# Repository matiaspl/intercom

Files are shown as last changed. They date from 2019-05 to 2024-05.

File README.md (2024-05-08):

# intercom
A githubbed version of DIY intercom system based on Murmur voice chat server and headless Mumble client running on Raspberry Pi 3 based beltpacks. It has been originally developed by Niclas Hallgren of [Institutionen för Kultur och Media](https://www.arcada.fi/sv/forskning/institutionen-kultur-och-media), [Arcada UAS](https://www.arcada.fi/en), Finland and funded by the university fund for technical education and research, TUF (Fonden för teknisk utbildning och forskning).

For more in-depth information head to https://web.archive.org/web/20231202153422/https://inside.arcada.fi/kultur-och-media/made-in-arcada-an-open-access-diy-intercom-system/ (courtesy of WebArchive) for a writeup by the author himself.

Since this project is based on unlicense license I thought saving it for future generations is worth 10 minutes of my time. I'm not the author nor am I in any way connected to the development (yet!). 

IArcada Intercom (https://www.youtube.com/watch?v=14hbYhLjQ8Y "Youtube Clip")

## What it's for
Providing communication for event production teams large and small with limited budget. Pro intercom solutions are very reliable but at the same time very expensive. Walkie-talkie PMR or UHF radios are OK and inexpensive, but they lack full-duplex partyline communication. And full duplex audio communication is a must for live TV production teams and for coordination teams on medium and large events. 

## How does it work
The soultion allows multichannel live full duplex communication over wifi networks utilizing [Mumble communication protocol](https://wiki.mumble.info/wiki/Protocol). The system has been tested with 12 beltpacks and 4 base stations, but should work with larger networks.
A single endpoint needs ~60 kb/s bandwidth, beltpacks are known to run for +18 hours on a single charge. Latency of 10-100 ms is to be expected.

## Room for improvements
- MPTCP and/or dual interface networking with gracefull failover (3G/4G + wifi)
- vibration alarm on call
- screensaver mode preventing OLED screen burn-in
- 'unlatch all' master base station button for rapid 'radio space' cleanup
- tally integration (vMix & ATEM)

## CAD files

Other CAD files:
basestation_setup/basestation_v3.f3d
beltpack_setup/beltpack_pi_2s.f3d

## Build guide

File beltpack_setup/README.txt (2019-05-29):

Files in this folder

ic_beltpack_pi3 - Python 3 files for beltpack
Gerber_Beltpack connector PCB_20181218103215.zip - Gerber files for Beltpack connector PCB
README.txt - This file
UNLICENSE - License information
beltpack_pi_2s.f3d - Fusion 360 3D case for beltpack
beltpack_rpi3.fzz - Fritzing breadboard view of beltpack
beltpack_rpi3_hardware_installation.pdf - Hardware installation guide
setup_beltpack_rpi3.pdf - Software installation guide

To open Fusion 360 files you need to download Fusion 360
https://www.autodesk.com/campaigns/fusion-360-for-hobbyists

To open Fritzing files you need to download Fritzing
http://fritzing.org/download/

Gerber files
Are sent to PCB factory for production
GerberLogix Gerber Viewver
https://www.easylogix.de/products_detail.php?prog_id=1

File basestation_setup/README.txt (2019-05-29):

Files in this folder

ic_basestation_pi3 - Python 3 files for basestation
Gerber_PCB_20181218104959.zip - Gerber files for Basestation connector PCB
README.txt - This file
UNLICENSE - License information
basestation_rpi3.fzz - Fritzing breadboard view of basestation
basestation_rpi3_hardware_installation.pdf - Hardware installation guide
basestation_v3.f3d - Fusion 360 3D case for basestation
setup_basestation_rpi3.pdf - Software installation guide

To open Fusion 360 files you need to download Fusion 360
https://www.autodesk.com/campaigns/fusion-360-for-hobbyists

To open Fritzing files you need to download Fritzing
http://fritzing.org/download/

Gerber files
Are sent to PCB factory for production
GerberLogix Gerber Viewer
https://www.easylogix.de/products_detail.php?prog_id=1

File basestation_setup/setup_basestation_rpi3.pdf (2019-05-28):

## Setup the software for the intercom base station

Requirements:
You have setup the server (Mumble, Mosquitto, Node.js) according to the server setup guide
Raspberry Pi 3 with Ethernet (tested with 3B), required hardware and software
Download the latest Raspbian Stretch Lite image from https://www.raspberrypi.org/downloads/raspbian/

This guide assumes that you are using a Windows computer but both Mac and Linux can be used (you just have to find the tools needed). The setup is tested with Raspbian Stretch Lite image built on the 2018-06-27. When copying code from the blue fields remember to check that there are no whitespace characters (invisible spaces) at the end of the lines because that can break the code.

Etcher https://etcher.io/ is recommended to write the image to the sd card. Insert the card into the Raspberry Pi, connect a keyboard and monitor and power up, after a few seconds the Raspberry will resize the partition to fill the card used and reboot. After the reboot you will see a login screen prompting for a username, use pi as username and raspberry as password. The first task is to setup the Raspberry Pi as needed. Write the command below and press enter

sudo raspi-config

You will now see a menu like this

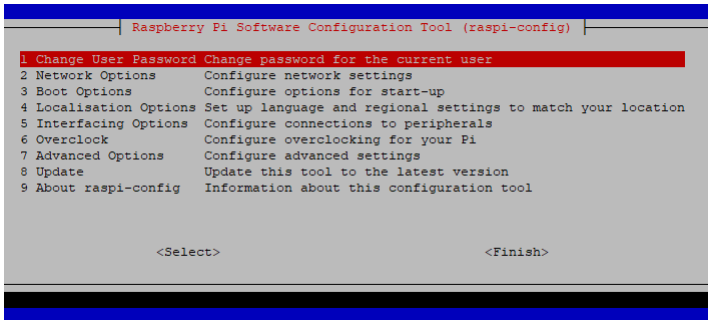
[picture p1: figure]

## 1. Configure the Raspberry

1 Change User Password (to something you remember)
2 Network Options
N1 Hostname (base stations should be named icbs1, icbs2… use icbs1 to follow this guide) 4 Localisation Options
I2 Timezone
I3 Change Keyboard-Layout
5 Interfacing options
P2 SSH Enable
P5 I2C Enable
7 Advanced options
A5 Resolution -> 1280x720 60Hz 16:9

Do NOT reboot on exit

## 2. Change I2C bus speed

sudo pico /boot/config.txt

Change line

dtparam=i2c_arm=on
to

dtparam=i2c_arm=on,i2c_arm_baudrate=400000

Save file (CTRL+x)

## 3. Set a static IP address

sudo pico /etc/dhcpcd.conf

Uncomment the example static IP configuration and use a IP that you are allowed to use
interface eth0
static ip_address=192.168.10.71/24
static routers=192.168.10.254
static domain_name_servers=8.8.8.8

Save file (CTRL+x) and reboot

sudo reboot

You should now have a IP address (look for the line My IP address is:xxxx)

You can now decide if you prefer to work with the keyboard and screen or continue the setup over SSH (using for example putty https://www.chiark.greenend.org.uk/~sgtatham/putty/ )

## 4. Update the system

sudo apt update
sudo apt dist-upgrade

### 5. Install xfce4 (a minimal graphical interface)

sudo apt install --no-install-recommends xserver-xorg
sudo apt install --no-install-recommends xinit
sudo apt install xfce4 xfce4-terminal tango-icon-theme gnome-icon-theme lightdm

## 6. Setup auto-login

sudo raspi-config

3 Boot Options
B1 Desktop / CLI
B4 Desktop Autologin

Finish and do NOT reboot

## 7. Install X11VNC

This gives a possibility to access the desktop from another computer

sudo apt install x11vnc

Set VNC password
x11vnc –storepasswd

enter desired password and save to /home/pi/.vnc/passwd

## 8. Autostart X11VNC

sudo pico /etc/xdg/autostart/x11vnc.desktop

[Desktop Entry]
Type=Application
Name=X11VNC
Comment=VNC
Icon=preferences-desktop-screensaver
Exec=x11vnc -bg -forever -noxdamage -ncache_cr -rfbauth /home/pi/.vnc/passwd TryExec=x11vnc
OnlyShowIn=XFCE;

Save file (CTRL+x)

## 9. Redirect error messages

Do not log error messages from the graphical interface to file to extend the sd card lifetime.

sudo pico /etc/X11/Xsession

point your ERRFILE to /dev/null IE. Line 77

comment out this line (add # before the line)

#exec >>"$ERRFILE" 2>&1

and add this below

exec >> /dev/null 2>&1

Save file (CTRL+x) and reboot (before this you should attach your usb sound card)

sudo reboot

## 10. Install Tightvnc

Download tightvnc on your windows computer from https://www.tightvnc.com/ -> Download, when installing choose only client.

## 11. Start Tightvnc

Start tightvnc and enter the IP number of your Raspberry Pi, you will be asked for your VNC password (set in step 7). When logged in choose “Use default config” in the popup window.

## 12. Setup audio devices

Click on the Applications button (upper left)

Applications -> Multimedia -> PulseAudio Volume Control

In the Configuration tab (press right arrow on keyboard to get to it)

bcm2835 ALSA Profile -> Off

USB Audio Device (CM108 Audio Controller) -> Analog Stereo Output + Analog Mono Input

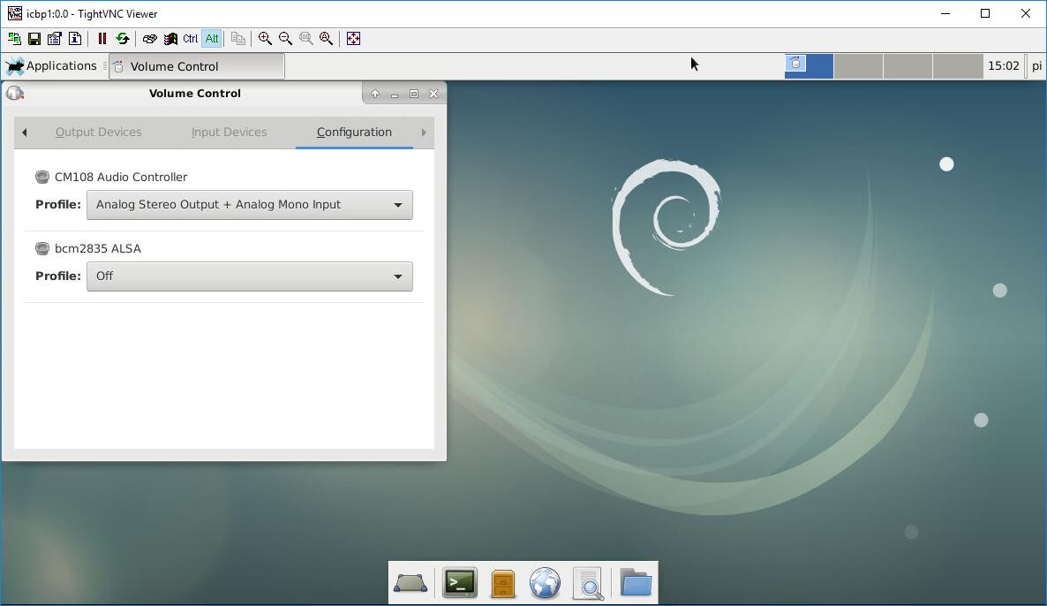
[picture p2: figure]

Close the PulseAudio Window

Enable echo cancellation for the sound card
sudo pico /etc/pulse/default.pa

add this line to the end of the file

load-module module-echo-cancel aec_method=webrtc

CTRL+x to save and reboot

sudo reboot

## 13. Create intercom folders

Go to Applications -> Terminal Emulator

mkdir ~/intercom
mkdir ~/intercom/certs
cd ~/intercom

## 14. Copy certificate files to the Raspberry Pi

The certificate was generated in the server setup guide

Download WinSCP (https://winscp.net/) on your Windows computer, install and start.

Under session choose SCP host name is your base station IP,

User name: pi, Password: (set in step 1)

When you are logged into the base station, on the left side you go to the folder where you exported the certs to in the server setup guide

On the right side you have your base station, double click intercom and then certs

Select all your certificates on the left side, right click and select Upload and OK

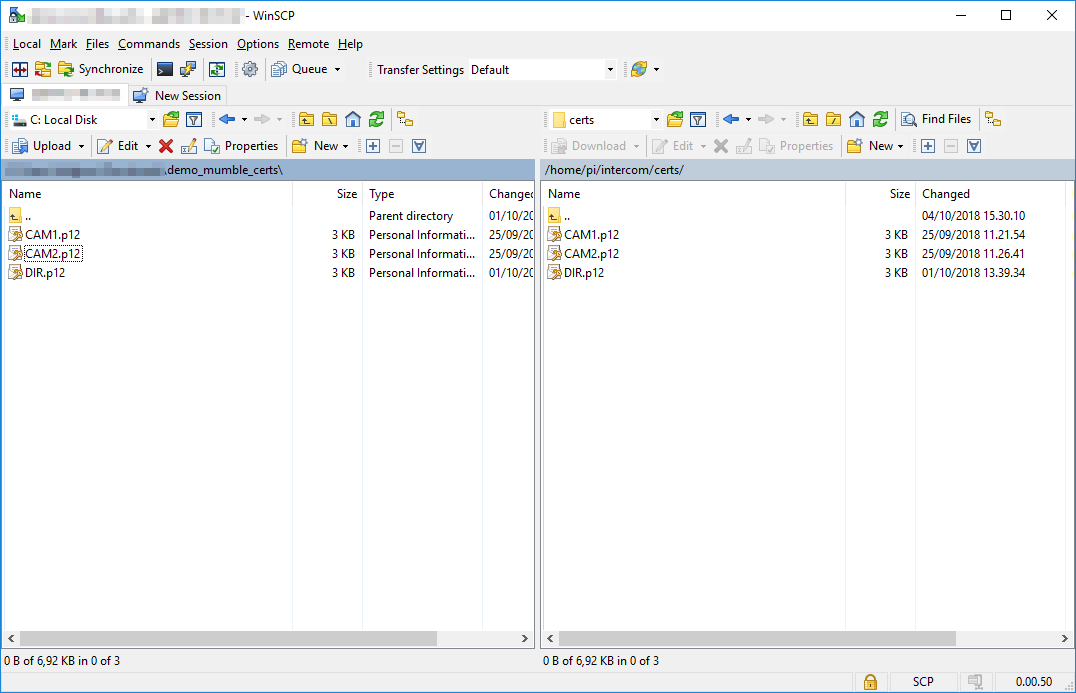
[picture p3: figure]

## 15. Install Mumble

Back to the Raspberry Pi and the terminal emulator

sudo apt install mumble

Close the terminal (click X in right corner)

## 16. Setup Mumble

When Mumble starts for the first time the Audio Tuning Wizard will appear, click next on the first introduction screen

Device selection

System: ALSA

Device [default] Playback/recording through the PulseAudio sound server

on both Input and Output device,

Uncheck positional audio -> Next

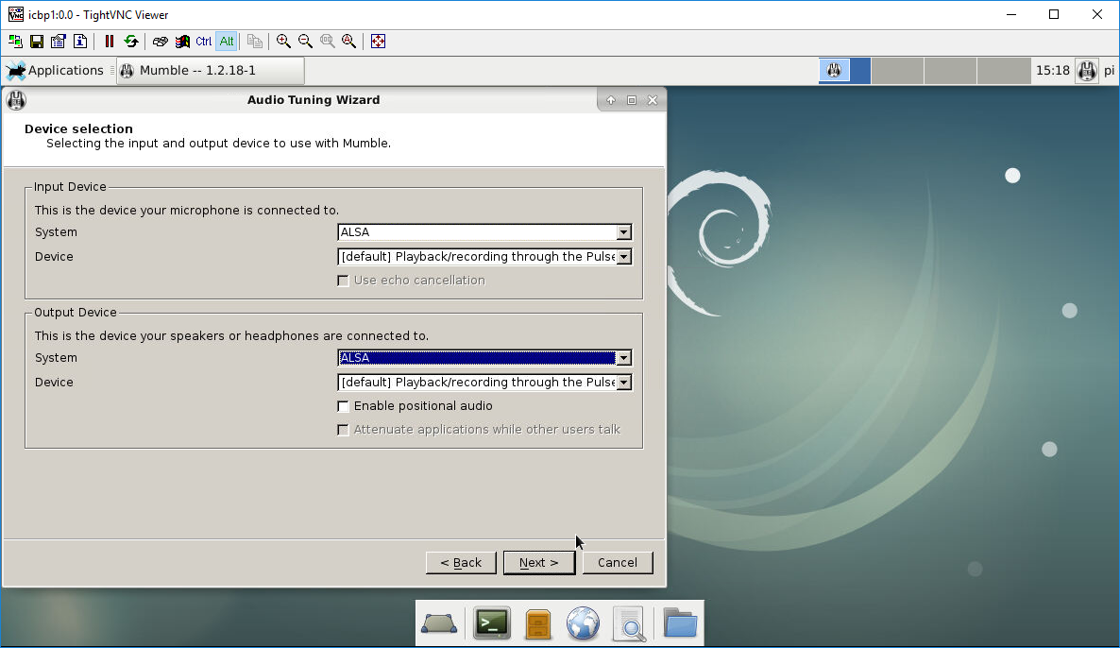
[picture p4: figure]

Set the buffer to 10ms (you will not hear anything here) -> Next

Let the microphone tuning be at its preset -> Next

Voice Acticity Detection, choose Push To Talk and click the white box next to it and press CTRL + 1 -> Next

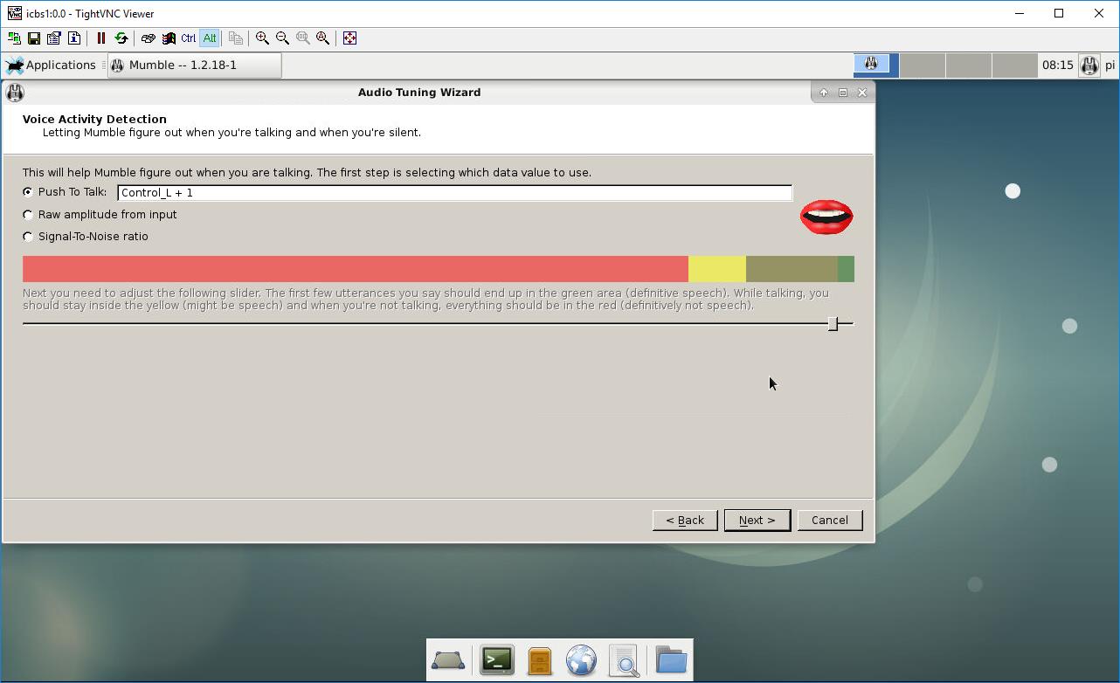
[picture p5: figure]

Quality and notifications, Quality settings -> High,

Uncheck Text-To-Speech and use sound instead -> Next

Choose if you want to submit anonymous statistics -> Finish

## 17. Import Mumble certificate

The Certificate Management should popup,

choose Import a certificate -> Next (you might have to scale the window to get to the next button)

Click Open and select the DIR certificate from /home/pi/intercom/certs/DIR.p12 -> Open -> Next

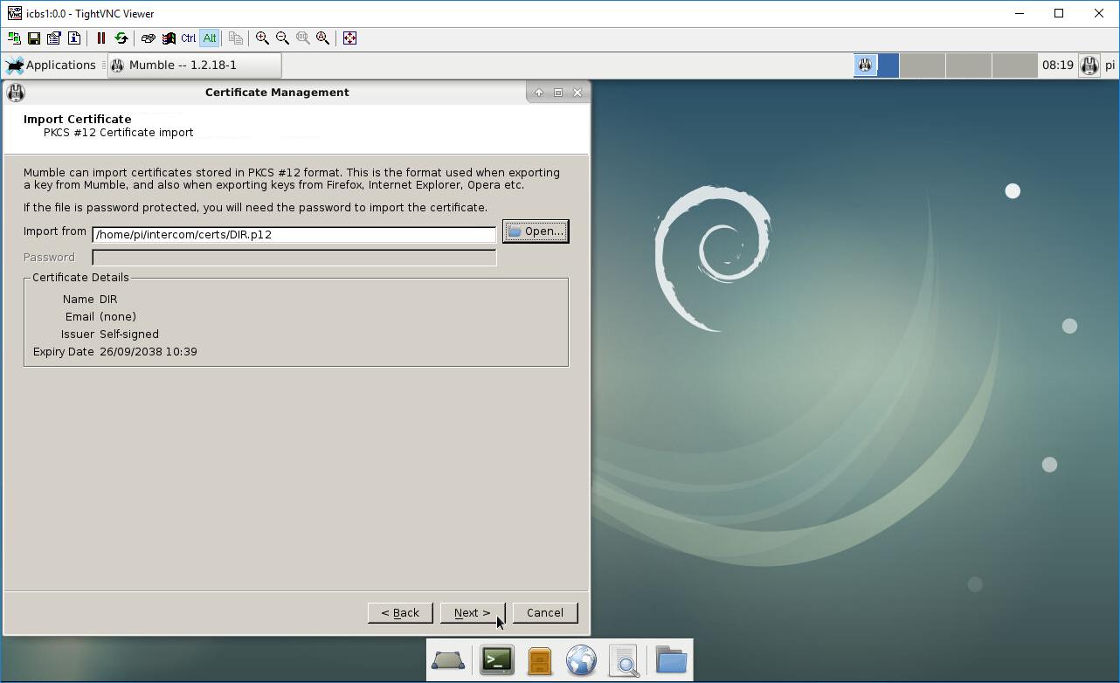
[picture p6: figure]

Click Finish

## 18. Connect to Mumble server

The Mumble Server Connect screen should have popped up, if not go to Server -> Connect

Click Add New,

Label: Intercom

Address: <YOURSERVERIP> in this example: 192.168.10.125

Port: 64738,

Username: DIR -> OK

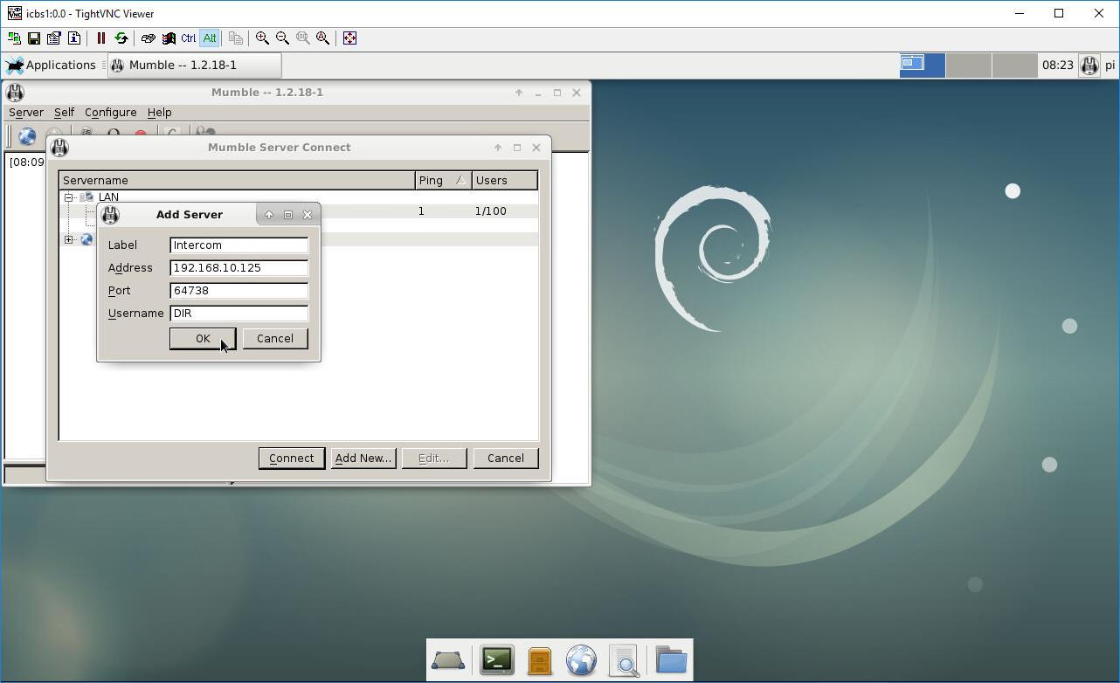
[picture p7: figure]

Under Favorite you should now see the Intercom server you just added, click Cancel and quit Mumble (Remember to ALWAYS quit/restart Mumble when making changes, settings are not saved when using power off/restart from command line).

Start Mumble again and connect to the Intercom server you just made, when you login to your server for the first time (with a new certificate) you will get a warning about the self-signed certificate, choose Yes and continue. You should now be logged in as DIR and put into the Video channel.

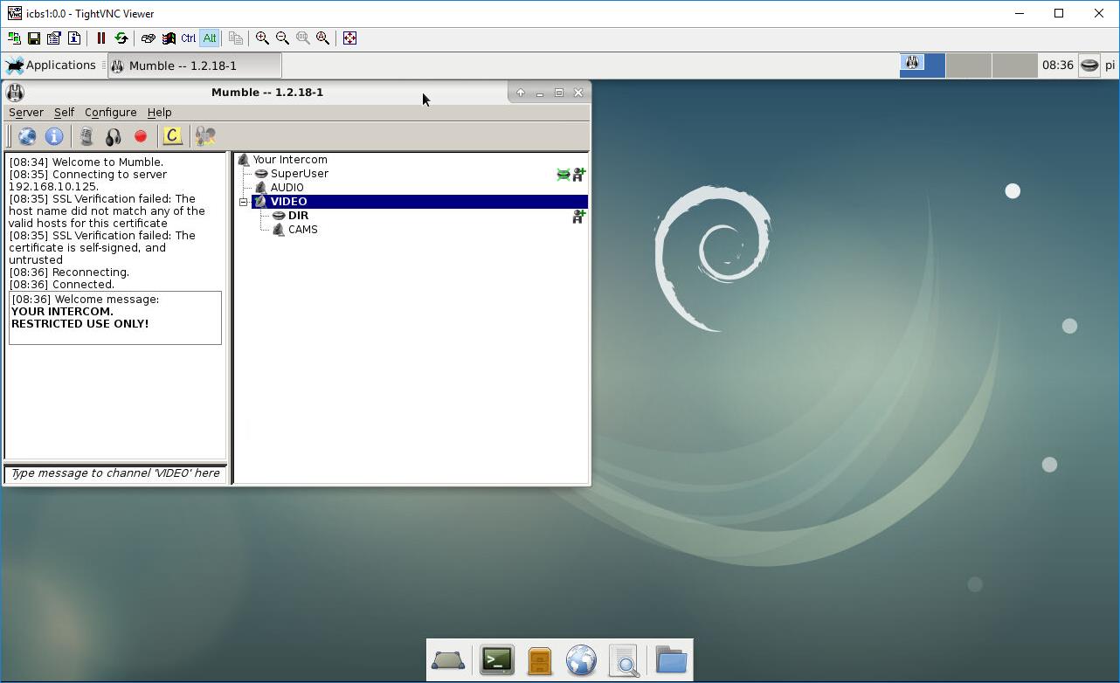
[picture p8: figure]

## 19. Configure Mumble, part 1

Under Configure->Settings->Click Advanced (down left)

Under Network, click Reconnect to last server on startup

Under Messages, set the matrix as in the picture, Notifications and Soundfile are the important ones, otherwise you will hear sounds every time a user joins/leaves a channel, etc.

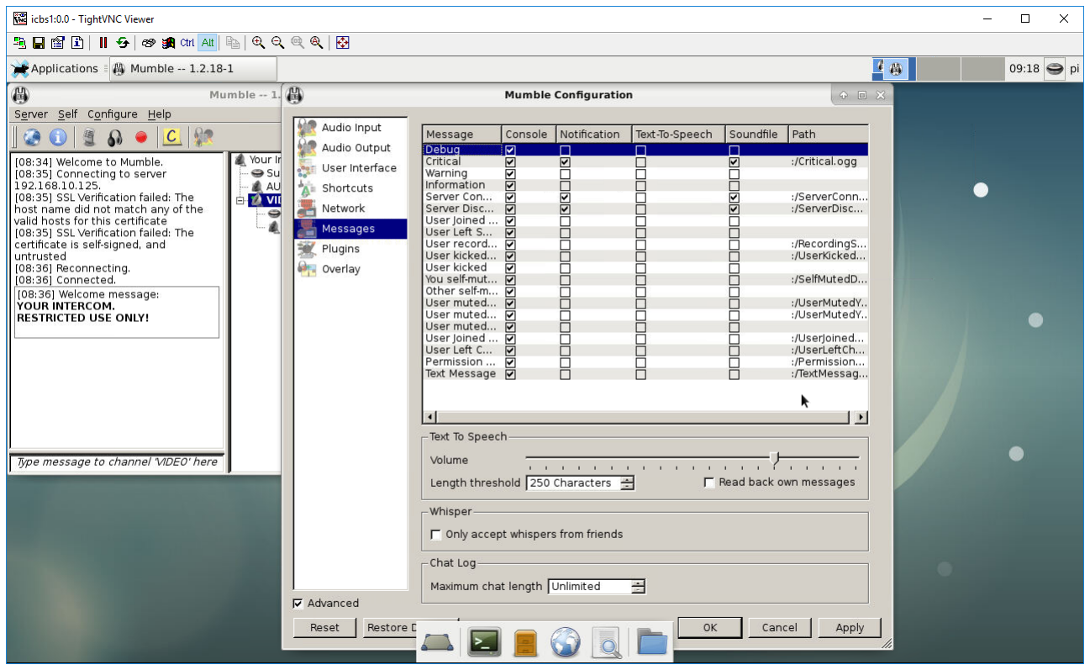
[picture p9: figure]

Apply->OK (and remember to quit/restart Mumble after this)

When Mumble is running we need to enable the echo cancellation (without a working echo cancellation the base station will get audio feedback and users talking to the base station will hear themselves if the base station is talking to them). This was setup in step 12.

Applications -> Multimedia -> PulseAudio Volume Control

Playback tab

Click USB Audio Device Analog Stereo button next to ALSA plug-in [mumble] Change dropdown ALSA Plugin [mumble] to the option that has echo cancelled.

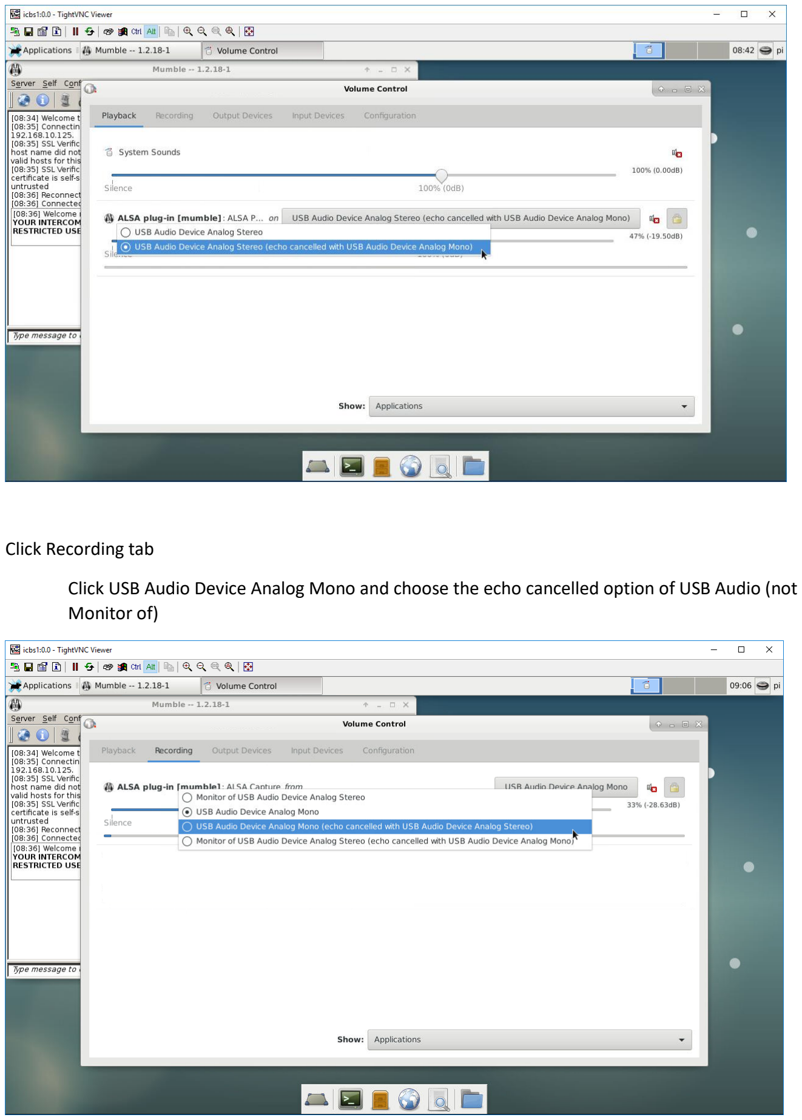
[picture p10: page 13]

Click Recording tab

Click USB Audio Device Analog Mono and choose the echo cancelled option of USB Audio (not Monitor of)

Close the Volume Control window with the X in the corner (there is no save button)

## 20. Autostart Mumble

Using Application->Terminal emulator (or using the terminal over ssh) enter the following lines

sudo pico /etc/xdg/autostart/start_mumble.desktop

[Desktop Entry]
Type=Application
Name=Mumble
Comment=Start Mumble client Icon=preferences-desktop-screensaver Exec=mumble
TryExec=mumble
OnlyShowIn=XFCE;

Save file (CTRL+x) and reboot

sudo reboot

Check (with tightvnc or screen) that Mumble starts and connects to server as DIR after reboot.

## 21. Correct session settings

Go to Applications->Settings->Session and Startup

Uncheck Automatically save session on logout under Logout Settings, and click Close

Go to Application->Terminal Emulator and write the following command

xfce4-settings-editor

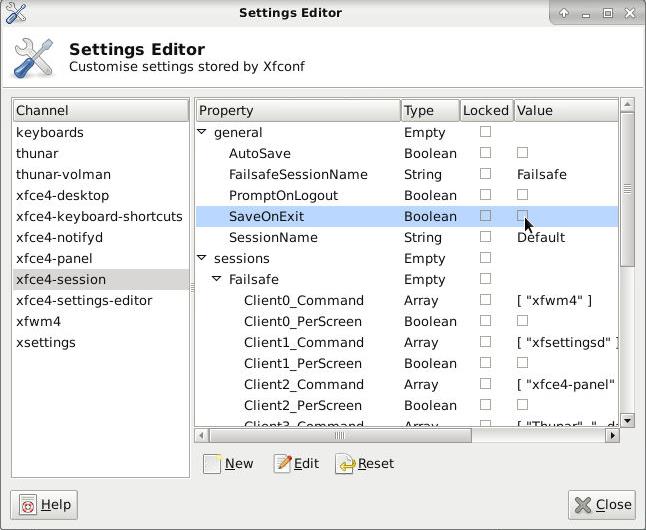
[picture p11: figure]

Under xfce4-session->Uncheck SaveOnExit if it is checked. Without this step, two Mumble clients will be running (one that is remembered from the last session and the new one that autostarts) and they will disconnect each other as only one user with that certificate can be logged in at the same time. Click Close and reboot once more to check that only one Mumble is running

sudo reboot

If everything is working, turn off the Raspberry Pi.

sudo poweroff

## 22. Install the Raspberry Pi into the enclosure

Check the base station hardware installation guide

## 23. Install python libraries

After the last step you can’t access the screen, as the Raspberry Pi is mounted in the base station enclosure. Instead you have to connect to it with putty (under hostname enter your base station IP) and click Open, login with pi and your password.

Install the OLED library
sudo apt install python3-dev python3-pip libfreetype6-dev libjpeg-dev sudo pip3 install --upgrade pip
sudo pip3 install --upgrade setuptools
sudo pip3 install --upgrade luma.oled

Install GUI automation libraries
sudo apt install libx11-dev libxtst-dev sudo pip3 install autopy3

Install MQTT library
sudo pip3 install paho-mqtt

## 24. Copy and extract base station script on Raspberry Pi

Use WinSCP on your Windows computer to copy the ic_basestation_pi3.zip file to the base station (/home/pi/intercom/ic_basestation_pi3.zip).

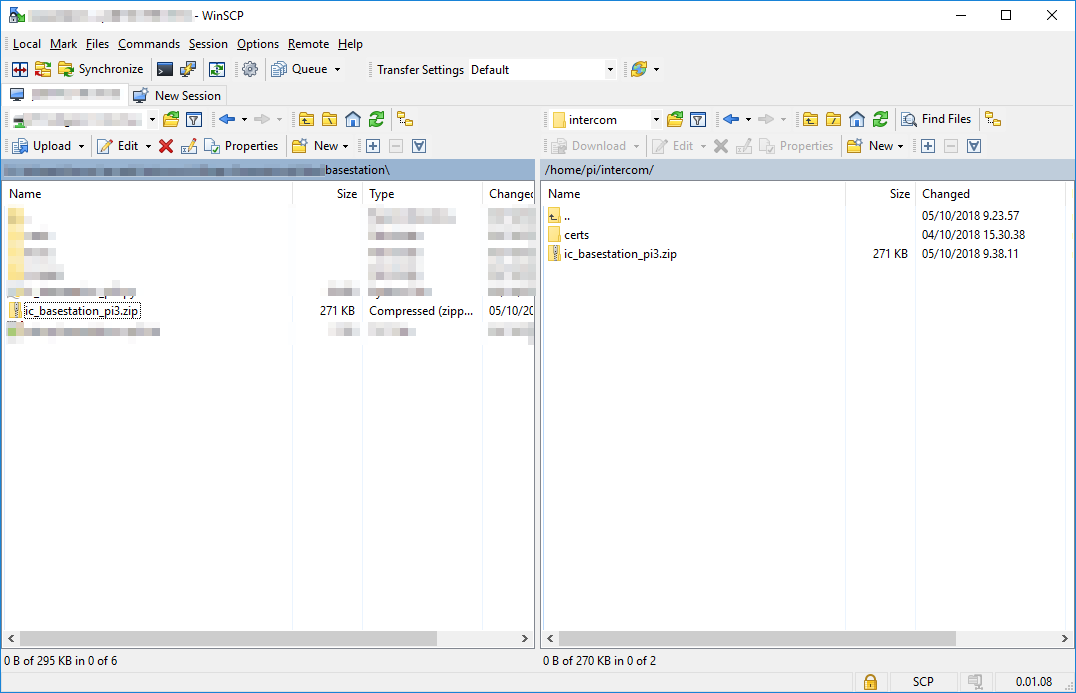
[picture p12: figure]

Back in putty

cd ~/intercom
unzip ic_beltpack_pi3.zip
rm ic_beltpack_pi3.zip

## 25. Copy MQTT server certificate

login in to your server (the example server is at 192.168.10.125)

ssh pi@192.168.10.125

(answer Yes)

Copy server cert to base station

scp /etc/mosquitto/certs/ca.crt pi@192.168.10.52:/home/pi/intercom
(replace IP with your base stations, answer yes and enter the base station password)

Disconnect from server CTRL+d and list the folder to check that the ca.crt is there

ls –la

## 26. Test the intercom script

Before you start the script you must edit it to connect to the right IP

pico ~/intercom/ ic_basestation_pi3.py

edit the following lines to match your setup:

mqttServer

mqttUser

mqttPass

Save file (CTRL+x) and start script

python3 ic_basestation_pi3.py

You should now see your IP and SRV UNAVAIL on the display. CTRL+c to quit

## 28. Make intercom startup script

pico ~/start_intercom.sh

#!/bin/bash

#START INTERCOM

DISPLAY=:1.0 XAUTHORITY=/home/pi/.Xauthority sudo /usr/bin/python3 /home/pi/intercom/ic_basestation_pi3.py &
#WAIT 30s AND SET MIC LEVEL

sleep 30
export PULSE_RUNTIME_PATH="/run/user/$(id -u)/pulse/"
# EXPERPIMENT WITH THE LAST NUMBER TO GET THE RIGHT MIC LEVEL (CAN BE DONE FROM CMD LINE) /usr/bin/pacmd set-source-volume 1 100000

observe that there should not be a line break after python3, everything should be on the same line like …/python3 /home/…

Save file (CTRL+x)

chmod +x start_intercom.sh

Make the intercom script start automatically

crontab -e

(choose 2 nano if asked)

add the following line to the end of the file

@reboot /home/pi/start_intercom.sh

CTRL+x to exit and save changes (do not change filename)

sudo reboot

After boot you should see a signal meter, the text UNKNOWN and your IP on the display

## 29. Configure the base station role

On your Windows computer open a browser and go to http://YOURSERVER_IP:3000

You now need to configure the base station, click the Wrench (the connection symbol on the left should now be green because the base station is online) on icbs1

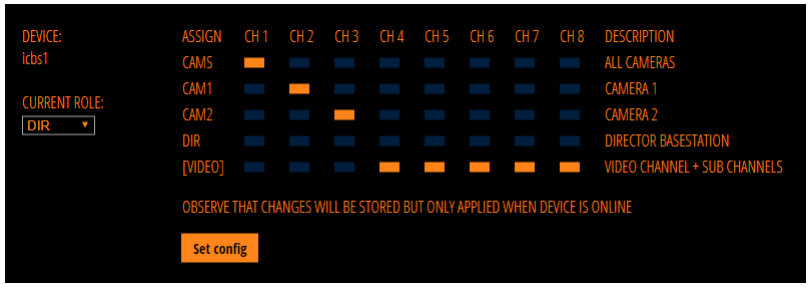
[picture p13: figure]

Select DIR as Role and the rest as the picture, click Set config

Your base station display should now be updated accordingly, it is now time to setup Mumble to match the script role and who you can talk to.

## 30. Continue to configure Mumble part 2

Connect with tightvnc to your base station, you want to talk to all cameras (CAMS) on channel 1, CAM1 on channel 2, CAM2 on channel 3 and the VIDEO channel with sub channels on 4-8. For this to work all users that you want to talk to needs to be connected to the server.

Let’s start with the CAMS channel

Under Shortcuts - > Change Push-to-Talk to Whisper/Shout (PTT transmits only the the same channel where the user is)

Under Shortcuts - > Click 3 dots under Data -> Choose Shout to channel -> Click on CAMS (UNDER VIDEO), ignore positional audio and OK

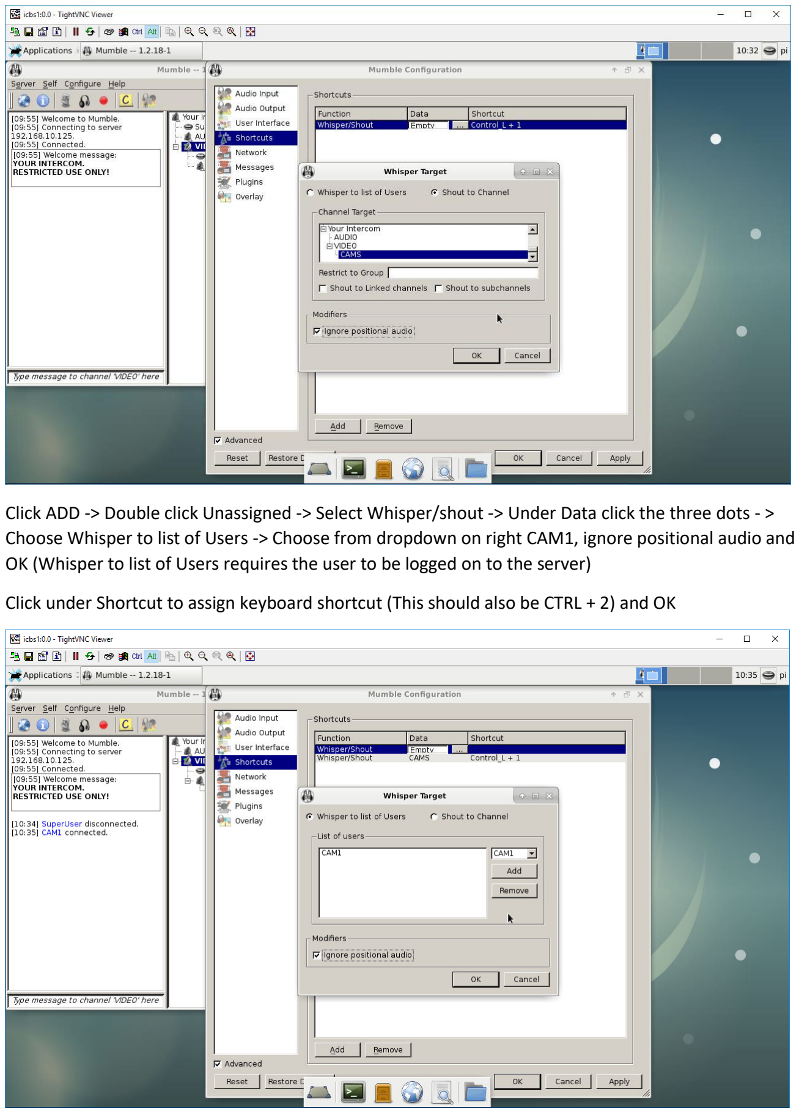
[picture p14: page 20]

Click ADD -> Double click Unassigned -> Select Whisper/shout -> Under Data click the three dots - > Choose Whisper to list of Users -> Choose from dropdown on right CAM1, ignore positional audio and OK (Whisper to list of Users requires the user to be logged on to the server)

Click under Shortcut to assign keyboard shortcut (This should also be CTRL + 2) and OK

Click ADD -> Double click Unassigned -> Select Whisper/shout -> Under Data click the three dots - > Choose Whisper to list of Users -> Choose from dropdown on right CAM2, ignore positional audio and OK

Click under Shortcut to assign keyboard shortcut (This should also be CTRL + 3)

Next we add the VIDEO channel (to channels 4-8) repeat the next steps 5 times but remember to change the shortcut CTRL+4,5,6,7,8

Click ADD -> Double click Unassigned -> Select Whisper/shout -> Under Data click the three dots - > Choose Shout to channel -> Click on VIDEO, (if you select Shout to subchannels users in both VIDEO and CAMS can hear you) ignore positional audio and OK

Click under Shortcut to assign keyboard shortcut

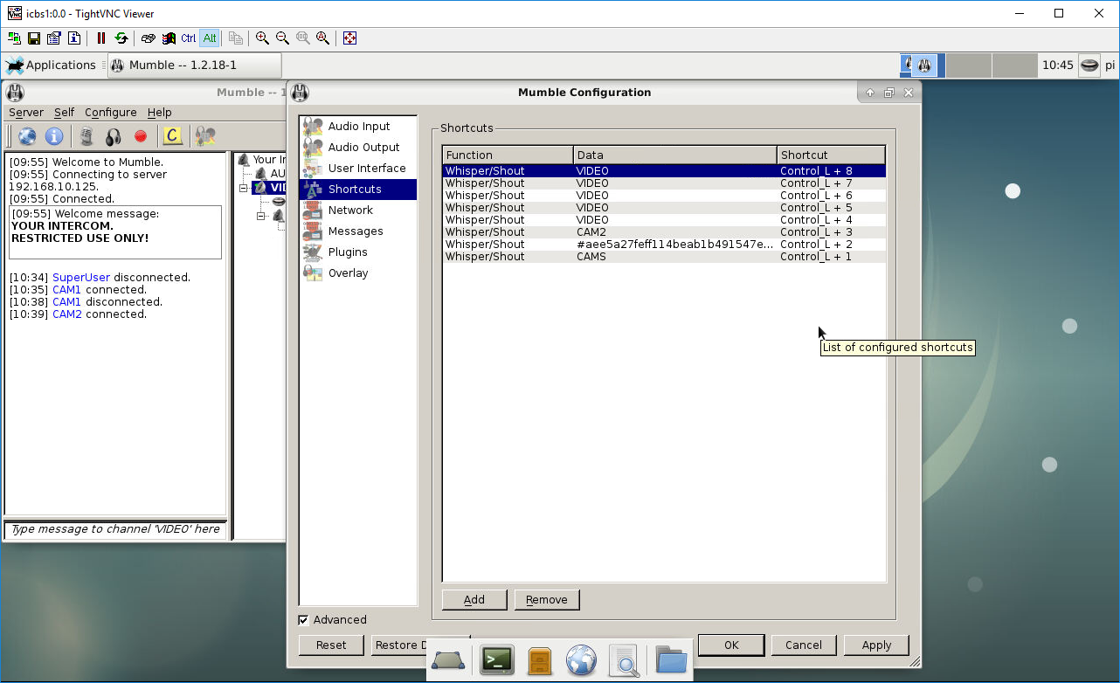
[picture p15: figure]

This is what it should look like after you are ready, in this picture CAM1 is no longer connected (had only one beltpack available when I did this guide so I had to change CAM1 to CAM2 after I assigned CAM1) and then you will see Mumbles unique id for the user. When the user is connected it will change to CAM1

Click Apply followed by OK (and remember to quit/start Mumble again)

It is possible to have own channels for users so you can use “Shout to channel” without needing the user to be online when doing the setup. Another good reason for having beltpack users in own channels are in case the beltpack user disconnects from Mumble. Mumble then stop broadcasting to that user. The python script that controls the talk buttons does not know if a user is disconnected from Mumble continues to send for example CTRL+2 (talk to CAM1), when the user connects to Mumble the users will not hear anything before the base station button is released and pressed again.

If you now hold down the first button above the display on the base station you can see that the icon before DIR turns blue (the director is talking)

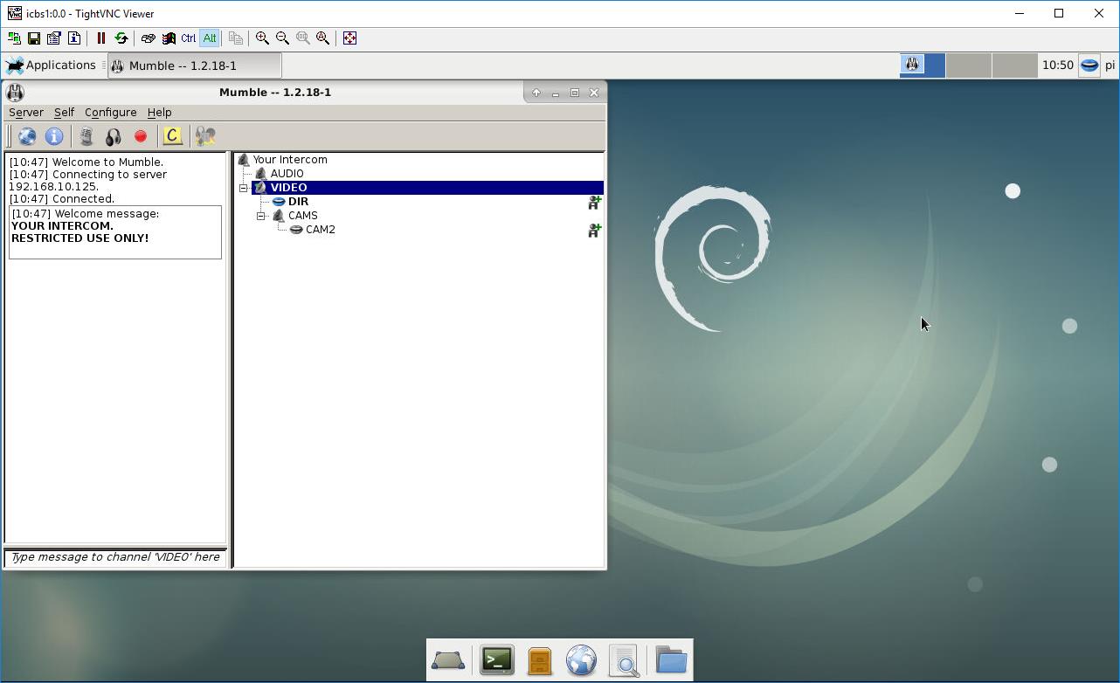
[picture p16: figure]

## 32. Conclusions

If everything works you are now ready to start using the base station. Now you can make an image of the sdcard so that you can easily duplicate it to other base stations.

Before making an image of the card, consider changing the IP, hostname and Mumble certificate to something not used normally. If you must deploy a new device during production the device the image is based on will disconnect when the new device with the same name/IP/Mumble certificate joins the network.

If you have access to a linux machine, you can use ddrescue and pishrink (replace sdc with where your sd card is found, use sudo dmsg to find out)

sudo ddrescue /dev/sdc beltpack.img rescue.log

Download and read more here https://github.com/Drewsif/PiShrink

sudo pishrink.sh beltpack.img

Pishrink (without the –s) will automatically expand to use the whole sd card when started for the first time

When you deploy the image to new devices you must remember to do the following things after deployment:

Change hostname (step 1) and IP (step 3)

Reboot to use the new name and IP

Load a new certificate in Mumble and setup who to talk to

Setup the same information in the intercom setup webgui.

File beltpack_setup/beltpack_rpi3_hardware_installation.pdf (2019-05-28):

## Assemble the intercom beltpack

Requirements:
Do not assemble the beltpack before told so in the Setup your intercom beltpack guide List of needed parts can be found in the end of this guide.

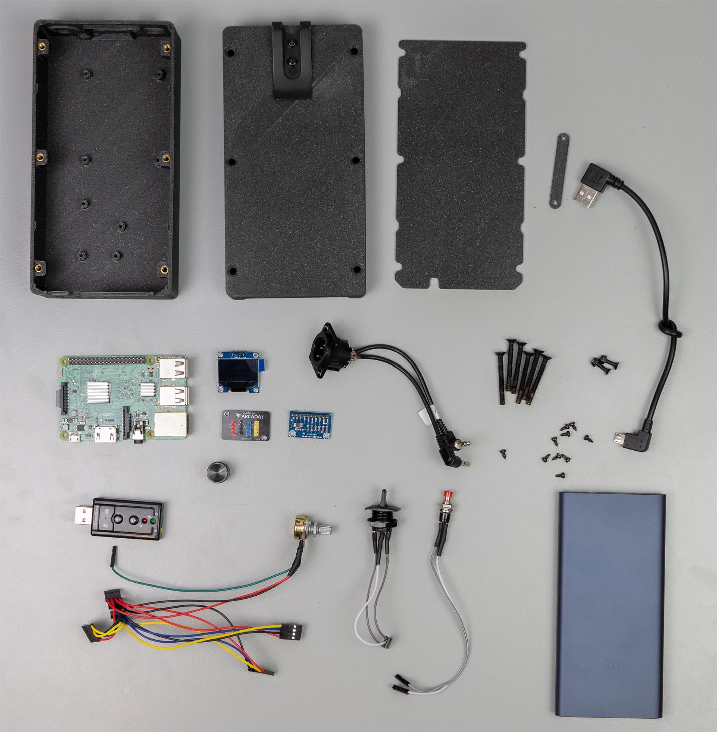
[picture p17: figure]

## 1. Insert brass insert nuts

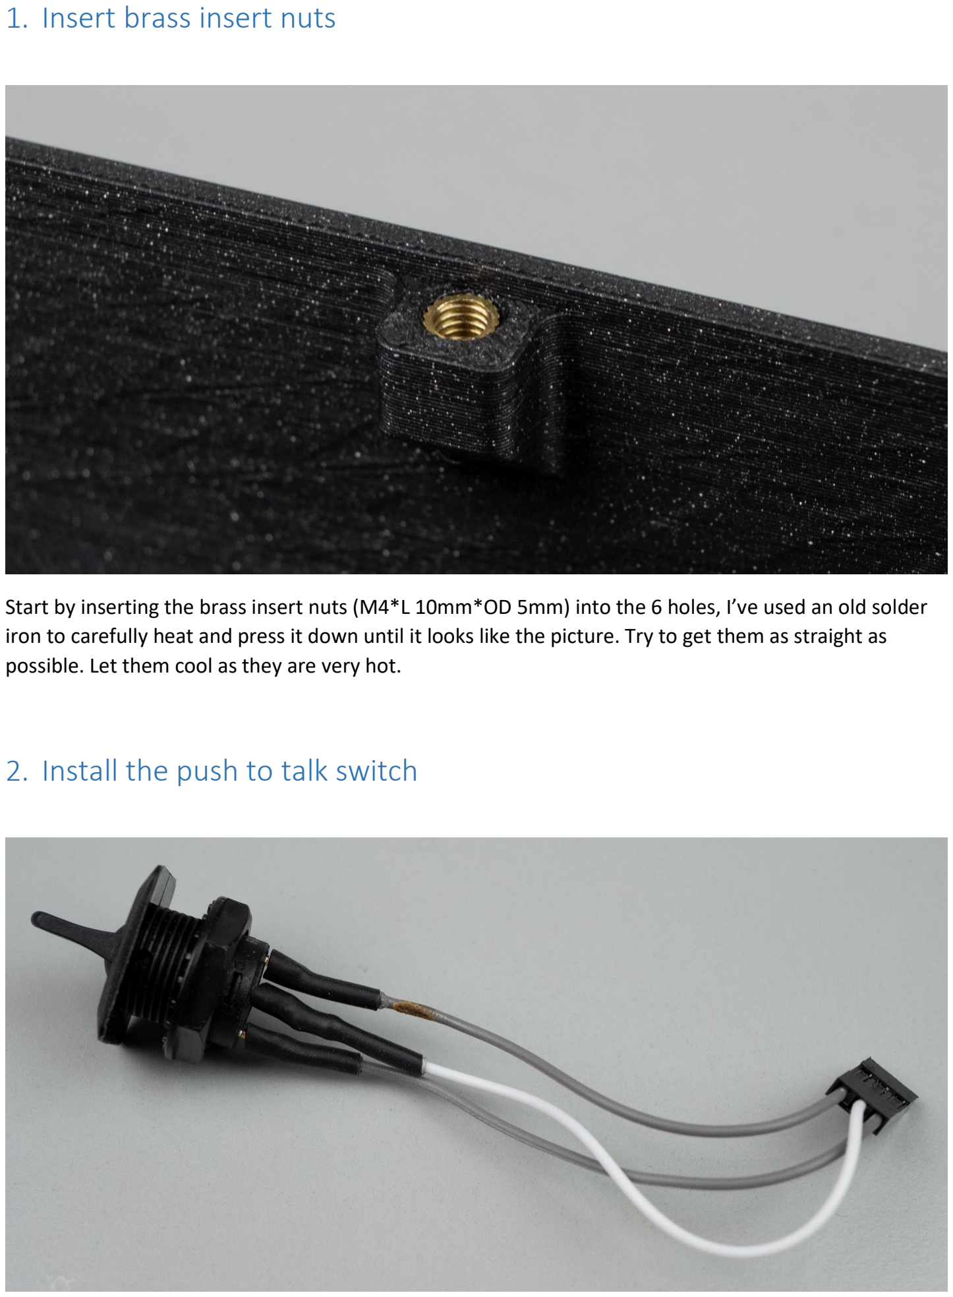
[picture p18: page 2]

Start by inserting the brass insert nuts (M4*L 10mm*OD 5mm) into the 6 holes, I’ve used an old solder iron to carefully heat and press it down until it looks like the picture. Try to get them as straight as possible. Let them cool as they are very hot.

## 2. Install the push to talk switch

The talk switch has off in the middle and talk to left and right (2 channels). In the picture the white cable provides 3.3V and has a 1k resistor soldered to the middle pin. This is to provide a little protection for the Raspberry in case it is connected to the wrong pin. The heat shrink tube to cover the pins, the other side is inserted into a 3 pin Dupont connector. Hint: Be careful not to melt the cable insulation as I did.

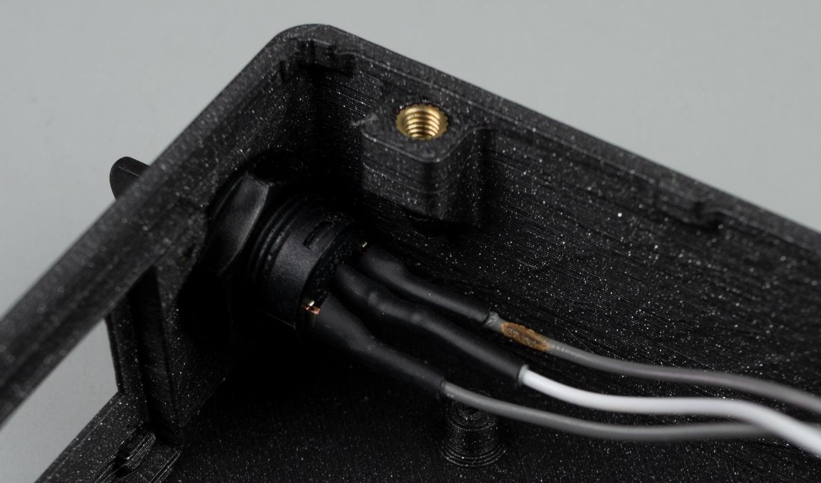
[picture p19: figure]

Insert the switch as shown.

## 3. Installing the XLR headset connector

Take a 3.5mm right angled cable and cut it in half (12-13cm should be enough but check before you cut), solder it to the XLR connector. XLR Pin 1 is connected to ground (check with a multimeter which color it is) on the 3.5mm plug that goes to the microphone on the soundcard and pin 2 is the microphone, solder the 2 remaining wires in the cable to that pin. Pin 3 is ground for the headphones and pin 4 to the left and right channels. Insert the cables through the XLR connectors hole and fasten with M3 screws and use M3 lock nuts on the inside.

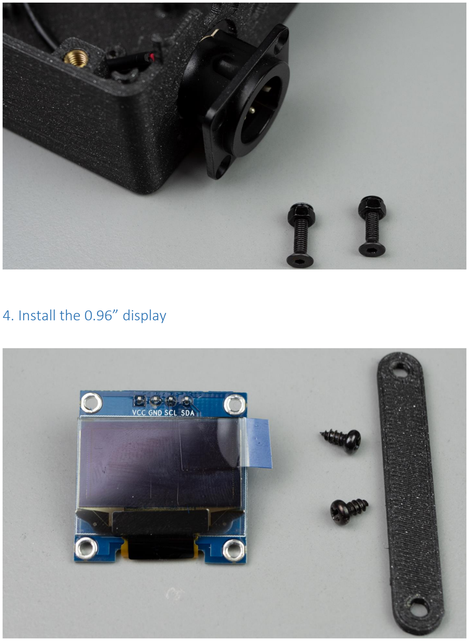
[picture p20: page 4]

## 4. Install the 0.96” display

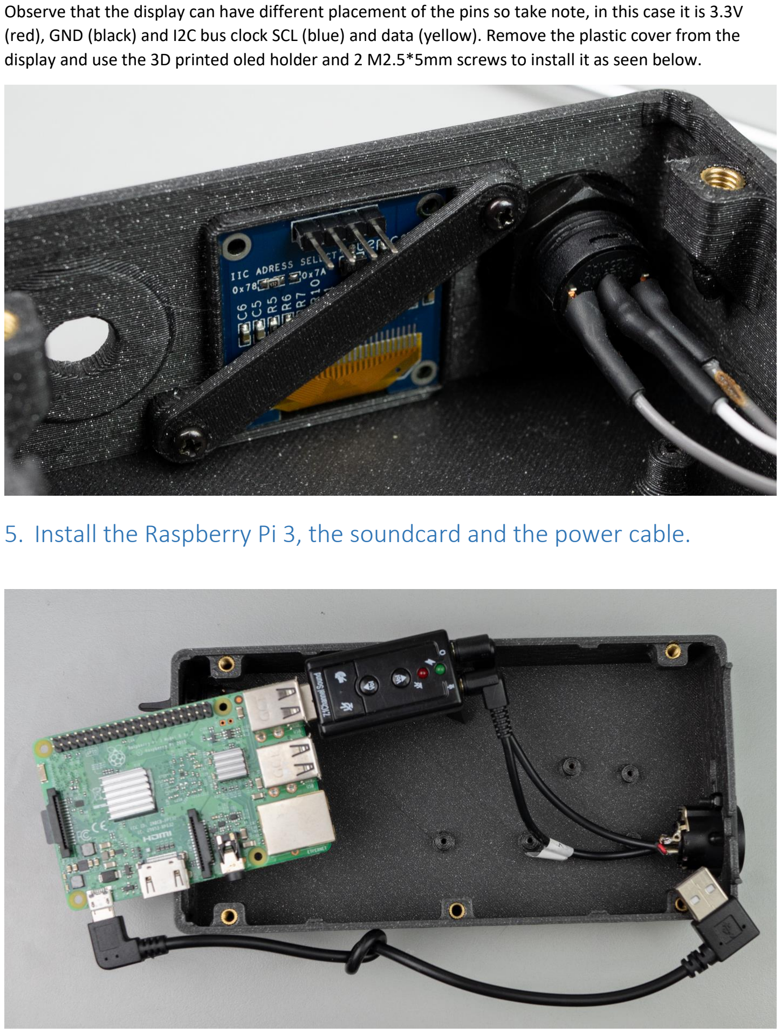
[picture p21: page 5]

Observe that the display can have different placement of the pins so take note, in this case it is 3.3V (red), GND (black) and I2C bus clock SCL (blue) and data (yellow). Remove the plastic cover from the display and use the 3D printed oled holder and 2 M2.5*5mm screws to install it as seen below.

5. Install the Raspberry Pi 3, the soundcard and the power cable.

Plug the micro USB cable into the Raspberry Pi, attach the USB soundcard and connect the 3.5mm cables from the XLR connector. Two heatsinks are installed to make the Raspberry run a bit cooler. Observe that in this guide the headphone and microphone cables are accidentally reversed in the soundcard. Carefully position the whole package into the enclosure and fasten the Raspberry Pi with 4 M2.5 (5mm) screws.

## 6. Connect the push to talk switch

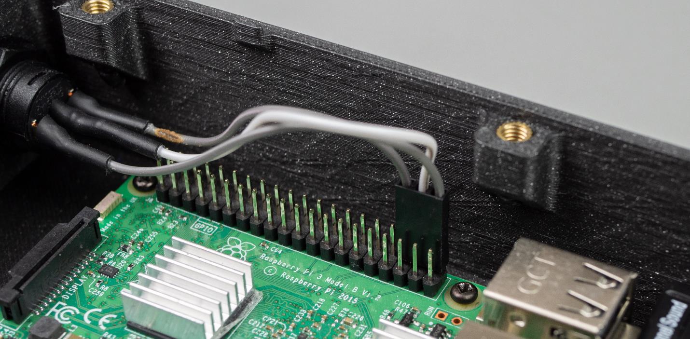
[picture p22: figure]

Connect the switch to pins 36,38 and 40 on the Raspberry Pi.

## 7. Install the breakout board and analog to digital converter

Because we need to split power and the I2C bus to multiple places I made a small PCB for the connectors but you can also use a prototype pcb to solder the connectors on, to the right the ADC for the volume control.

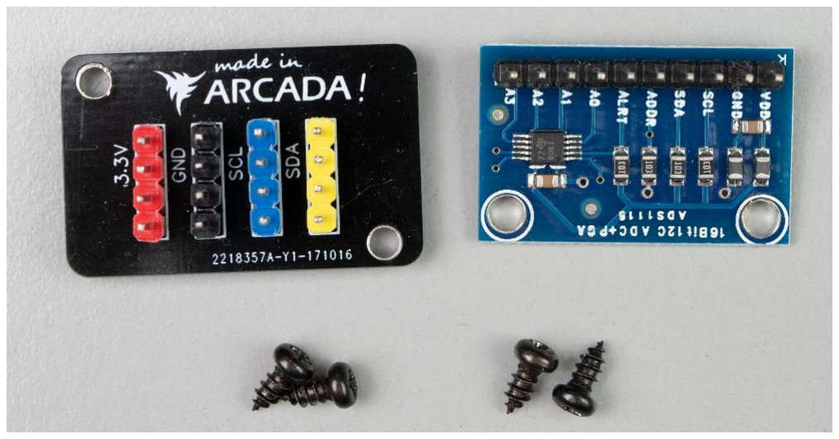
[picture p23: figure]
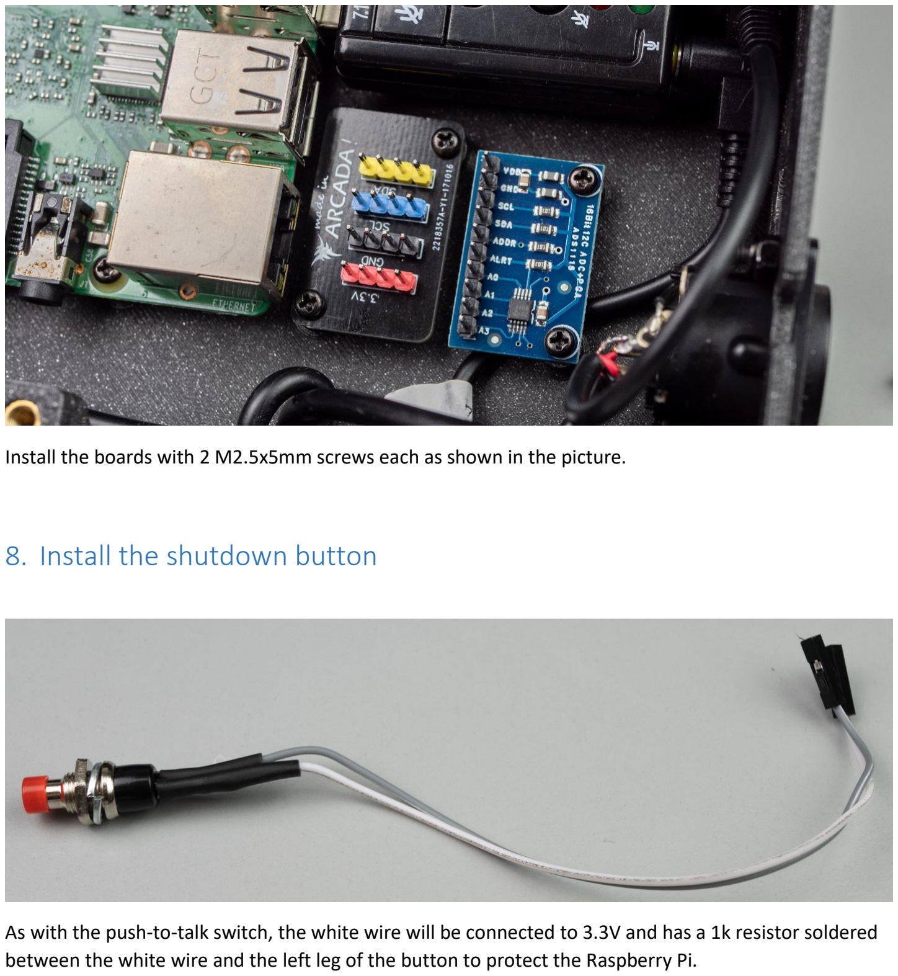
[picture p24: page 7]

Install the boards with 2 M2.5x5mm screws each as shown in the picture.

## 8. Install the shutdown button

As with the push-to-talk switch, the white wire will be connected to 3.3V and has a 1k resistor soldered between the white wire and the left leg of the button to protect the Raspberry Pi.

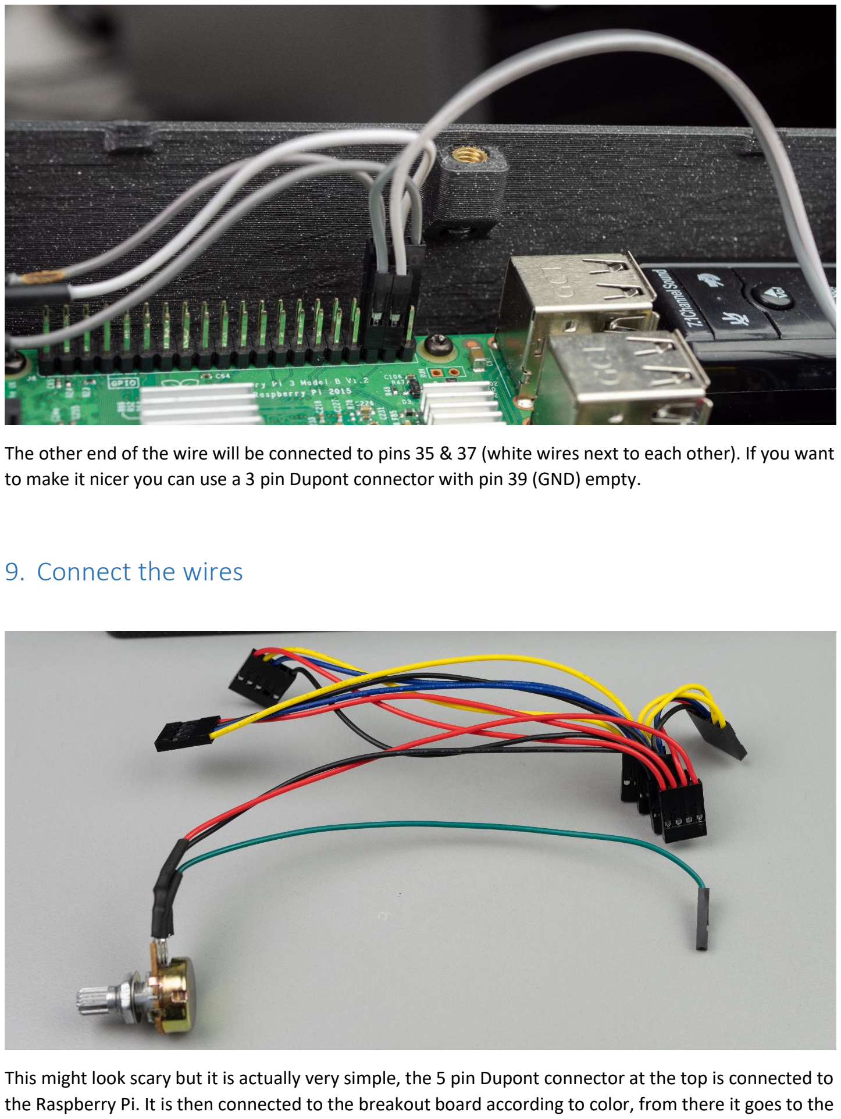
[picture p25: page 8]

The other end of the wire will be connected to pins 35 & 37 (white wires next to each other). If you want to make it nicer you can use a 3 pin Dupont connector with pin 39 (GND) empty.

## 9. Connect the wires

This might look scary but it is actually very simple, the 5 pin Dupont connector at the top is connected to the Raspberry Pi. It is then connected to the breakout board according to color, from there it goes to the

ADC, the display and the volume control board. Let’s take it step by step. You do not need to use multipin Dupont connectors but it makes them stay better and are easier to connect.

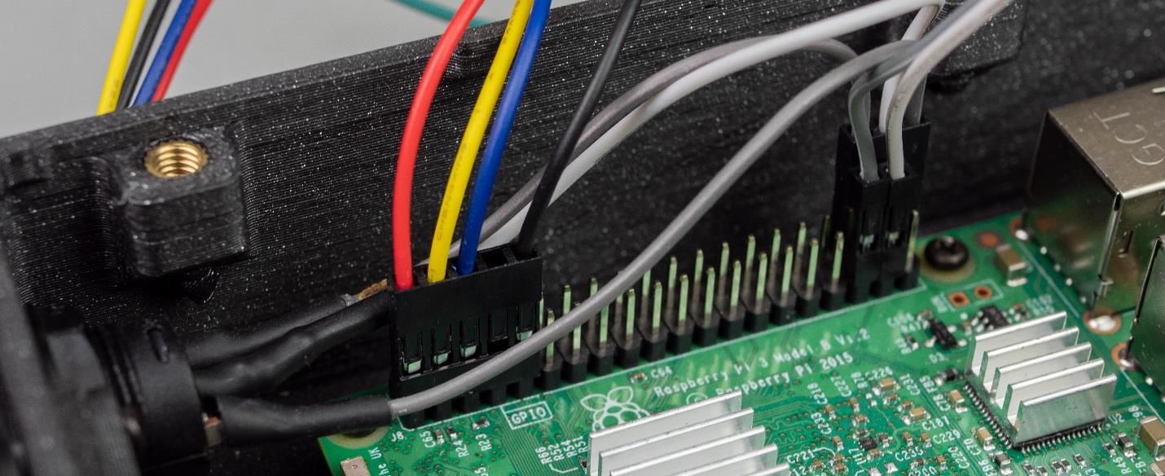
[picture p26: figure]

Start by connecting the 5 pin Dupont to the Raspberry Pi pin 1,3,5 and 9. Note that there is one empty pin between the blue and the black wire. We have now connected 3.3V, ground and the I2C data bus (yellow SDA and blue SCL).

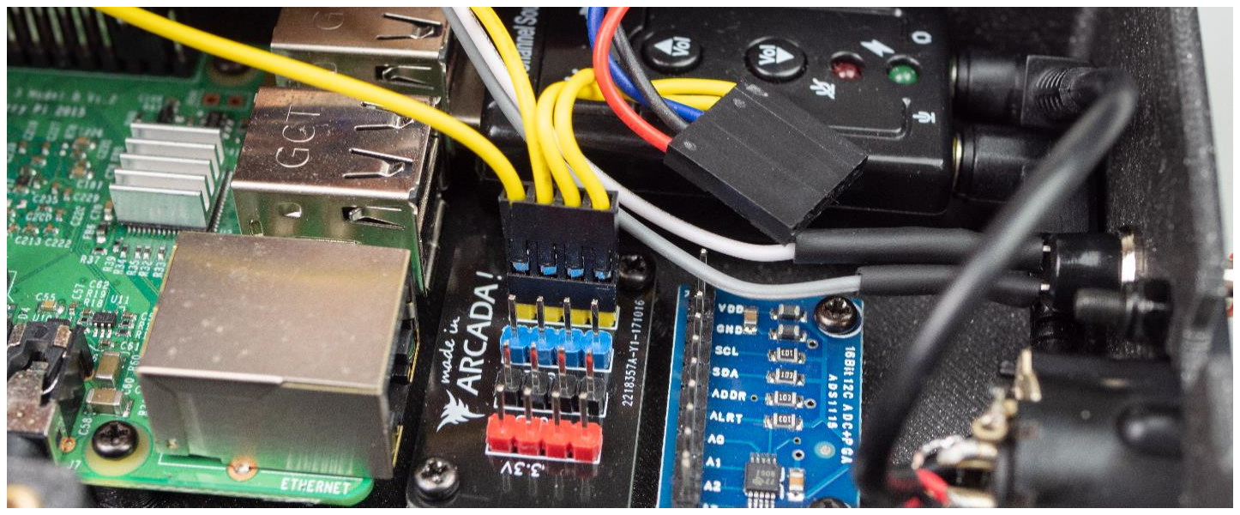
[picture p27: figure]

The yellow cable (SDA) connects to the yellow connector on the breakout board. Of the remaining 3 wires one go to the display and 2 to the ADC board (one to the SDA connector and one to the ADDR pin to change the modules I2C address from 0x48 to 0x4A). This is because in an earlier version of the beltpack there was an address issue but this should not actually be needed any more. If you decide not to connect SDA to the ADDR pin remember to change the I2C address in the volume_control.py script.

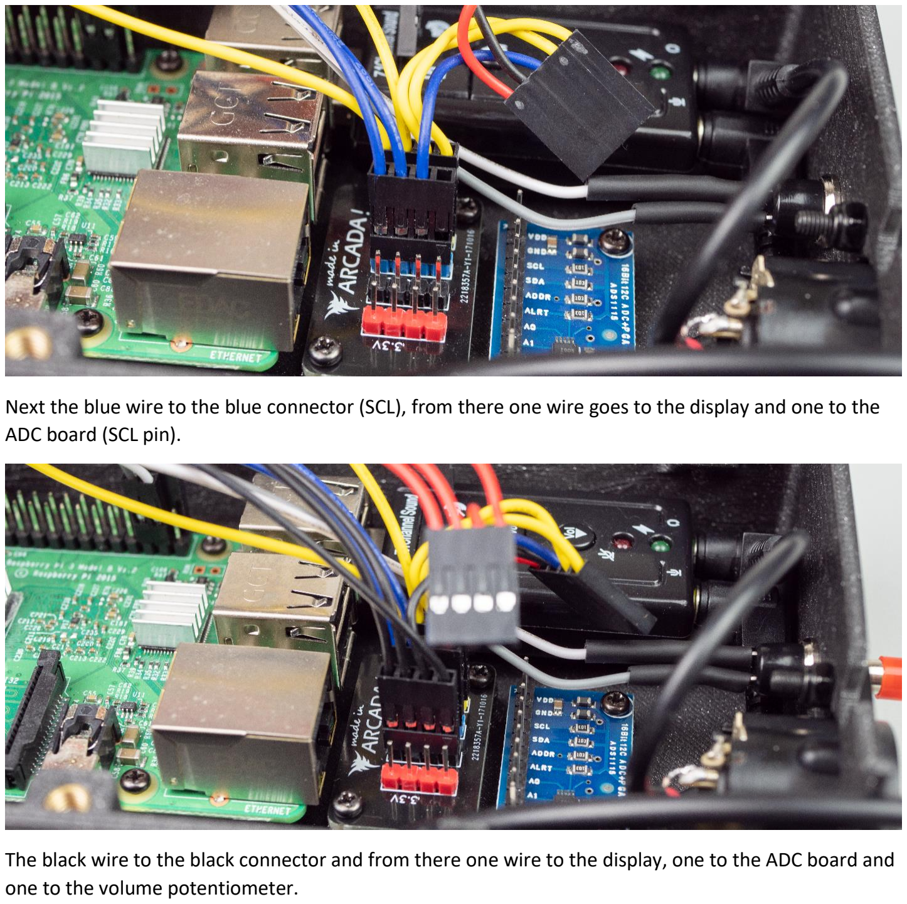
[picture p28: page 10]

Next the blue wire to the blue connector (SCL), from there one wire goes to the display and one to the ADC board (SCL pin).

The black wire to the black connector and from there one wire to the display, one to the ADC board and one to the volume potentiometer.

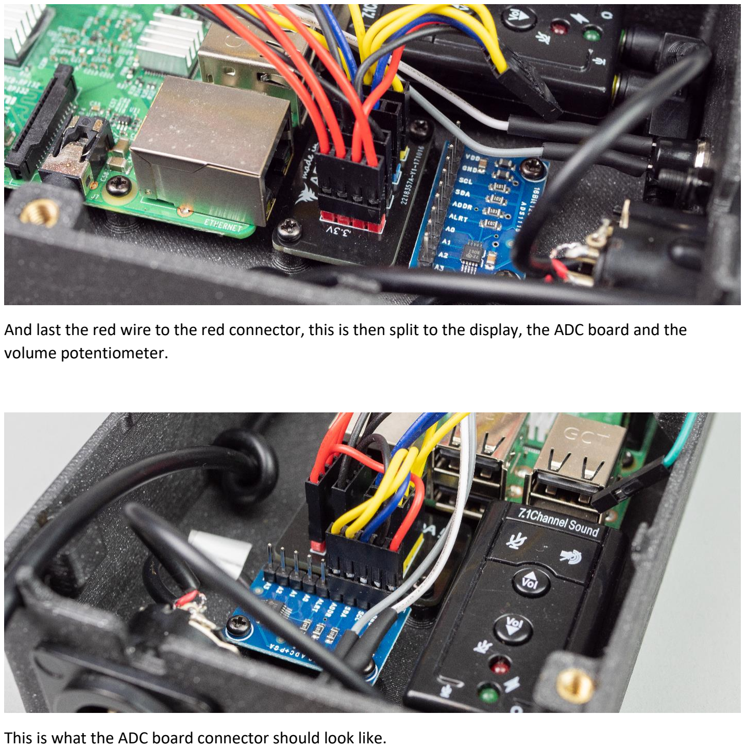
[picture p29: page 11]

And last the red wire to the red connector, this is then split to the display, the ADC board and the volume potentiometer.

This is what the ADC board connector should look like.

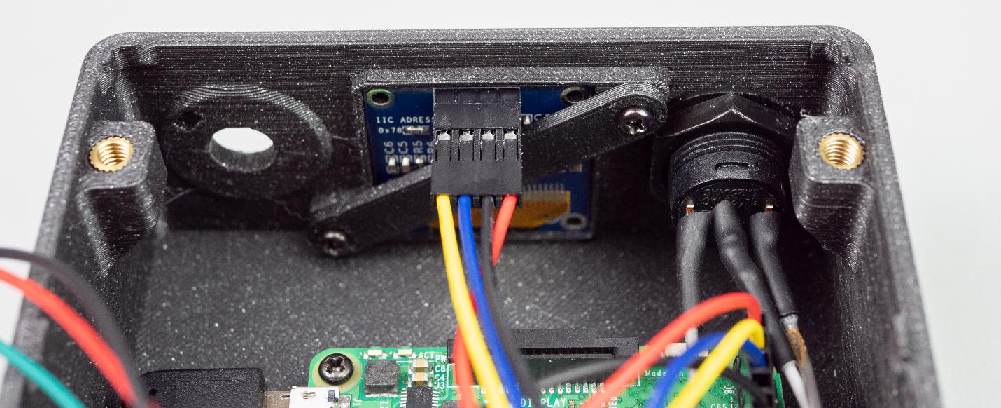
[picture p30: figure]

The display is connected as shown but remember to check that the pins on your display has the same order as pointed out in step 4. Also remember that the display is now seen from behind.

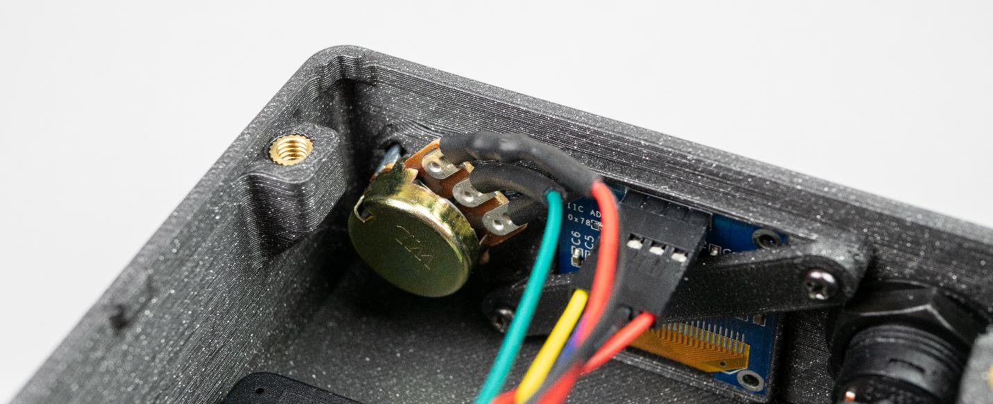
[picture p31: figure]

The 100k volume potentiometer installed, red wire (3.3V) has a 1k resistor on the wire for protection, the green wire is the output and is connected to the ADC pin A0. The black wire connected to the third pin on the potentiometer. This way we can adjust the voltage between 0V and 3.3V that is then converted to 0-100 in the volume control script that controls the soundcards output level.

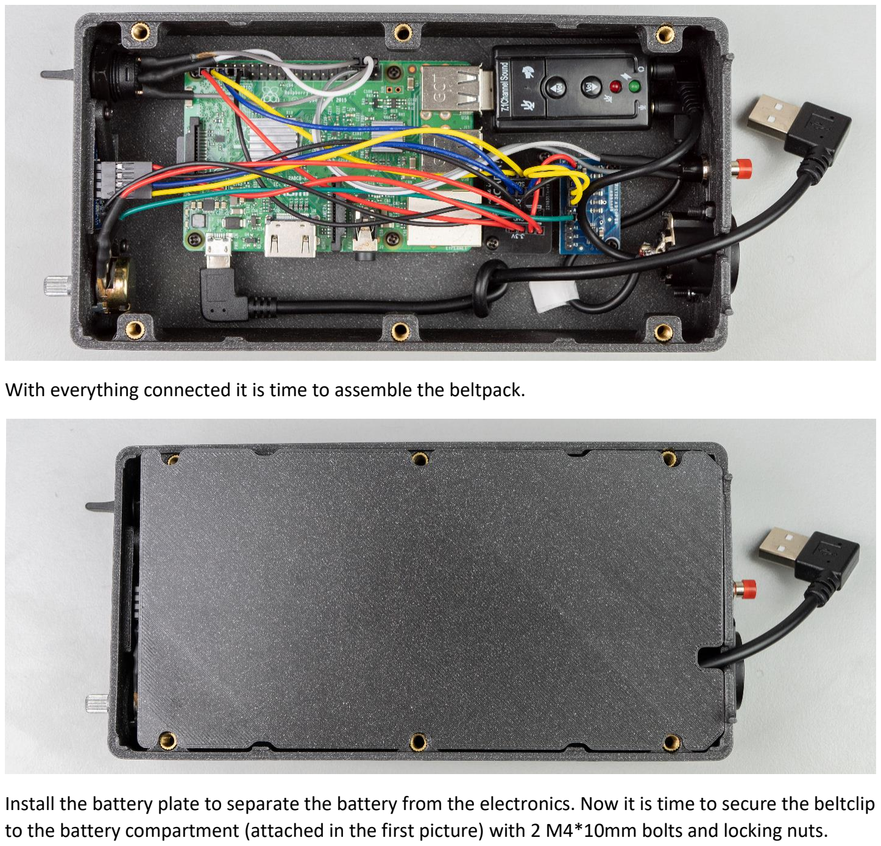
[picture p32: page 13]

With everything connected it is time to assemble the beltpack.

Install the battery plate to separate the battery from the electronics. Now it is time to secure the beltclip to the battery compartment (attached in the first picture) with 2 M4*10mm bolts and locking nuts.

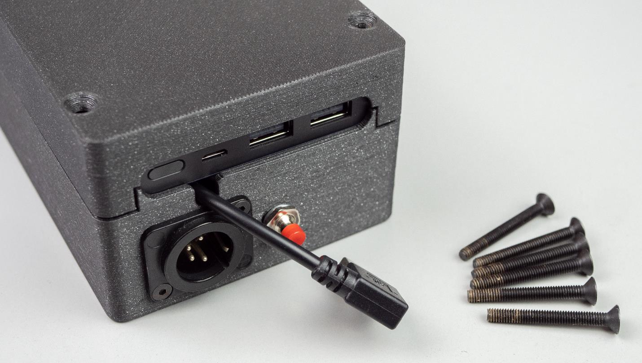
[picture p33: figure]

Put the battery on top the the battery plate and finally attach the battery cover with 6 M4*35mm bolts.

Parts needed:
10 pcs M2.5*5mm screws
2 pcs M3*10mm countersunk bolts 2 pcs M3 lock nuts
6 pcs M4*35mm countersunk bolts
6 pcs M4*10*5 Brass insert nuts https://www.aliexpress.com/item/200pcs-lot-Brass-Knurl-Nuts-M4-10mm-L-5mm-OD-Metric-Threaded-Nuts-Insert-Round-Shape/32651619949.html (https://www.aliexpress.com/item/200pcs-lot-Brass-Knurl-Nuts-M4-10mm-L-5mm-OD-Metric-Threaded-Nuts-Insert-Round-Shape/32651619949.html)
1 pcs USB 2.0 Left Angle A Male 90 Degrees to Micro Left Angle M Cable Data Cord https://www.aliexpress.com/item/2PCS-USB-2-0-Left-Angle-A-Male-90-Degrees-to-Micro-Left-Angle-M-Cable/32784619132.html (https://www.aliexpress.com/item/2PCS-USB-2-0-Left-Angle-A-Male-90-Degrees-to-Micro-Left-Angle-M-Cable/32784619132.html)
1 pcs 100k Linear potentiometer (volume control + knob) https://www.aliexpress.com/item/Free-shipping-10pcs-Single-potentiometer-B100K-amppotentiometer-handles-type-b-20MM/1954510106.html (https://www.aliexpress.com/item/Free-shipping-10pcs-Single-potentiometer-B100K-amp-potentiometer-handles-type-b-20MM/1954510106.html)
3 pcs 1k resistors
1 pcs breakout board or prototype pcb (Gerber files included)
1 pcs 4pin male Neutrik XLR NC4MD-L-BAG-1
1 pcs ADS1115 ADC board
https://www.aliexpress.com/item/16-Bit-I2C-ADS1115-Module-ADC-4-channel-with-Pro-Gain-Amplifierfor-Arduino-RPi-1PCS/32718837389.html (https://www.aliexpress.com/item/16-Bit-I2C-ADS1115-Module-ADC-4-channel-with-Pro-Gain-Amplifier-for-Arduino-RPi-1PCS/32718837389.html)
1 pcs 0.96” white i2c Oled display (ssd1306) https://www.aliexpress.com/item/Free-Shipping-White-Blue-Whiteand-Blue-color-0-96-inch-128X64-OLED-Display-Module-For-arduino/32713614136.html (https://www.aliexpress.com/item/Free-Shipping-White-Blue-Whiteand-Blue-color-0-96-inch-128X64-OLED-Display-Module-For-arduino/32713614136.html)
1 pcs Momentary push button (power off) https://www.aliexpress.com/item/IMC-Hot-10Pcs-Red-Cap-SPST-Momentary-Mini-Pushbutton-Switch-DC-50V-0-3A/32816983756.html (https://www.aliexpress.com/item/IMC-Hot-10Pcs-Red-Cap-SPST-Momentary-Mini-Pushbutton-Switch-DC-50V-0-3A/32816983756.html)
1 pcs 3 Position momentary MON-OFF-MON switch https://www.aliexpress.com/item/5Pcs-Black-R13-402-Momentary-ON-OFF-ON-3Pin-3Position-SPDT-Round-Toggle-Switch/32817966368.html (https://www.aliexpress.com/item/5Pcs-Black-R13-402-Momentary-ON-OFF-ON-3Pin-3Position-SPDT-Round-Toggle-Switch/32817966368.html)
1 pcs Linux compatible USB soundcard https://www.aliexpress.com/item/External-USB-Audio-Card-Sound-Adapter-Virtual-7-1ch-USB-Microphone-3-5mm-Jack-Converter-for/32658791595.html (https://www.aliexpress.com/item/External-USB-Audio-Card-Sound-Adapter-Virtual-7-1ch-USB-Microphone-3-5mm-Jack-Converter-for/32658791595.html)
1 pcs Raspberry Pi 3B (or 3B+)
1 pcs Xiaomi 10000mAh powerbank (IMPORTANT!! case is made for PLM09ZM version)
1 pcs Headset Superlux HMC 660 X used but can be whatever you want (you need to replace connectors with one 4 pin XLR)
1 pcs black belt clip
https://www.theclip.com/store/metal-belt-clip-661-tempered-belt-clip.html
Heat shrink tube
https://www.aliexpress.com/item/1meter-lot-2-4mm-Heat-Shrink-Tube-with-Glue-Adhesive-Lined-3-1-Shrinkage-Dual-Wall/32818131285.html (https://www.aliexpress.com/item/1meter-lot-2-4mm-Heat-Shrink-Tube-with-Glue-Adhesive-Lined-3-1-Shrinkage-Dual-Wall/32818131285.html)
0.5m 3.5mm Male to male right angle cable (XLR to soundcard) https://www.aliexpress.com/item/LEORY-0-5m-3-5mm-Plug-Aux-Audio-Cable-Right-Angle-Male-To-Male-Headphone-Extension/32911832454.html (https://www.aliexpress.com/item/LEORY-0-5m-3-5mm-Plug-Aux-Audio-Cable-Right-Angle-Male-To-Male-Headphone-Extension/32911832454.html)
Different sizes Dupont terminal connectors
Connection wire, different colors (white,grey,red,black,yellow,blue,gren) AWG 24 recommended but can also be readymade female-female wires with Dupont connectors. The problem with readymade cables is that they are sold as fixed length and not the length you need. It is usually better to buy wire (AWG24) and Dupont female connectors and crimp yourself.
UL1007 24AWG connection cable (red,green,blue,yellow, black) https://www.aliexpress.com/item/10-Meters-UL-1007-Wire-24AWG-1-4mm-PVC-Wire-Electronic-Cable-UL-Certification-Insulated-LED/32821442881.html (https://www.aliexpress.com/item/10-Meters-UL-1007-Wire-24AWG-1-4mm-PVC-Wire-Electronic-Cable-UL-Certification-Insulated-LED/32821442881.html)
SN-2549 Crimp tool for Dupont connectors https://www.aliexpress.com/item/SN-2549-Pin-Crimping-Tool-2-54mm-3-96mm-4-8mm-28-18awg-0-08-1/32823519191.html (https://www.aliexpress.com/item/SN-2549-Pin-Crimping-Tool-2-54mm-3-96mm-4-8mm-28-18awg-0-08-1/32823519191.html)
Female Dupont connector
https://www.aliexpress.com/item/Hot-100x-Dupont-Jumper-Cable-Wire-Female-Pin-Connector-2-54mm-copper-DIY-Good-Quality-wholesale/1850210835.html (https://www.aliexpress.com/item/Hot-100x-Dupont-Jumper-Cable-Wire-Female-Pin-Connector-2-54mm-copper-DIY-Good-Quality-wholesale/1850210835.html)
Dupont terminal connector kit https://www.aliexpress.com/item/620pcs-Dupont-Connector-2-54mm-Dupont-Cable-Jumper-Wire-Pin-Header-Housing-Kit-Male-Crimp-Pins/32839071531.htm (https://www.aliexpress.com/item/620pcs-Dupont-Connector-2-54mm-Dupont-Cable-Jumper-Wire-Pin-Header-Housing-Kit-Male-Crimp-Pins/32839071531.htm)

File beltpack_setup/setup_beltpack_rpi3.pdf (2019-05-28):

## Setup the software for the intercom beltpack

Requirements:
You have setup the server (Mumble, Mosquitto, Node.js) according to the server setup guide
Raspberry Pi 3 (tested with 3B, 3A+ will not fit the case as it is), required hardware and software
Download the latest Raspbian Stretch Lite image from https://www.raspberrypi.org/downloads/raspbian/

This guide assumes that you are using a Windows computer but both Mac and Linux can be used (you just have to find the tools needed). The setup is tested with Raspbian Stretch Lite image built on the 2018-10-09. When copying code from the blue fields remember to check that there are no whitespace characters (invisible spaces) at the end of the lines because that can break the code.

Etcher https://etcher.io/ is recommended to write the image to the sd card. Insert the card into the Raspberry Pi, connect a keyboard and monitor and power up, after a few seconds the Raspberry will resize the partition to fill the card used and reboot. After the reboot you will see a login screen prompting for a username, use pi as username and raspberry as password. The first task is to setup the Raspberry Pi as needed. Write the command below and press enter

sudo raspi-config

You will now see a menu like this


## 1. Configure the Raspberry

1 Change User Password (to something you remember)
2 Network Options
N1 Hostname (beltpacks should be named icbp1, icbp2… use icbp1) 4 Localisation Options
I2 Timezone
I3 Change Keyboard-Layout
I4 Change Wi-fi Country
5 Interfacing options
P2 SSH Enable
P5 I2C Enable
7 Advanced options
A5 Resolution -> 1280x720 60Hz 16:9

Do NOT reboot on exit

## 2. Change I2C bus speed

sudo pico /boot/config.txt

Change line

dtparam=i2c_arm=on
to

dtparam=i2c_arm=on,i2c_arm_baudrate=400000

Save file (CTRL+x)

## 3. Setup WiFi

sudo pico /etc/wpa_supplicant/wpa_supplicant.conf

add to bottom of file and replace with your SSID and password

network={
ssid="YOURSSID"
psk="YOURNETWORKPASSWORD"
}

Save file (CTRL+x) and reboot

sudo reboot

You should now have a IP address (look for the line My IP address is:xxxx). Consider using a static IP if possible.

You can now decide if you prefer to work with the keyboard and screen or continue the setup over SSH (using for example putty)

## 4. Update the system

sudo apt update
sudo apt dist-upgrade

### 5. Install xfce4 (a minimal graphical interface)

sudo apt install --no-install-recommends xserver-xorg
sudo apt install --no-install-recommends xinit
sudo apt install xfce4 xfce4-terminal tango-icon-theme gnome-icon-theme lightdm

## 6. Setup auto-login

sudo raspi-config

3 Boot Options
B1 Desktop / CLI
B4 Desktop Autologin

Finish and do NOT reboot

## 7. Install X11VNC

This gives a possibility to access the desktop from another computer

sudo apt install x11vnc

Set VNC password
x11vnc –storepasswd

enter desired password and save to /home/pi/.vnc/passwd

## 8. Autostart X11VNC

sudo pico /etc/xdg/autostart/x11vnc.desktop

[Desktop Entry]

Type=Application
Name=X11VNC
Comment=VNC
Icon=preferences-desktop-screensaver
Exec=x11vnc -bg -forever -noxdamage -ncache_cr -rfbauth /home/pi/.vnc/passwd TryExec=x11vnc
OnlyShowIn=XFCE;

Save file (CTRL+x)

### 9. Redirect error messages (do not log to file to extend the SD card lifetime)

sudo pico /etc/X11/Xsession

point your ERRFILE to /dev/null IE. Line 77

comment out this line (add # before the line)

#exec >>"$ERRFILE" 2>&1

and add this below

exec >> /dev/null 2>&1

Save file (CTRL+x) and reboot (before this you should attach your usb sound card)
sudo reboot

## 10. Install Tightvnc

Download tightvnc on your windows computer from https://www.tightvnc.com/ -> Download, when installing choose only client.

## 11. Start Tightvnc

Start tightvnc and enter the IP number of your Raspberry Pi, you will be asked for your VNC password. When logged in choose “Use default config” in the popup window.

## 12. Setup audio devices

Click on the Applications button (upper left)

Applications -> Multimedia -> PulseAudio Volume Control

In the Configuration tab (press right arrow on keyboard to get to it)

bcm2835 ALSA Profile -> Off

USB Audio Device (CM108 Audio Controller) -> Analog Stereo Output + Analog Mono Input


### Close the PulseAudio Window

## 13. Create intercom folders

Go to Applications -> Terminal Emulator

mkdir ~/intercom
mkdir ~/intercom/certs
cd ~/intercom

## 14. Copy certificate files to the Raspberry Pi

The certificate was generated in the server setup guide.

Download WinSCP (https://winscp.net/) on your Windows computer, install and start.

Under session choose SCP host name is your beltpack IP,

User name: pi, Password: (set in step 1)

When you are logged into the beltpack, on the left side you go to the folder where you exported the certs to in the server setup guide

On the right side you have your beltpack, double click intercom and then certs

Select all your certificates on the left side, right click and select Upload and OK

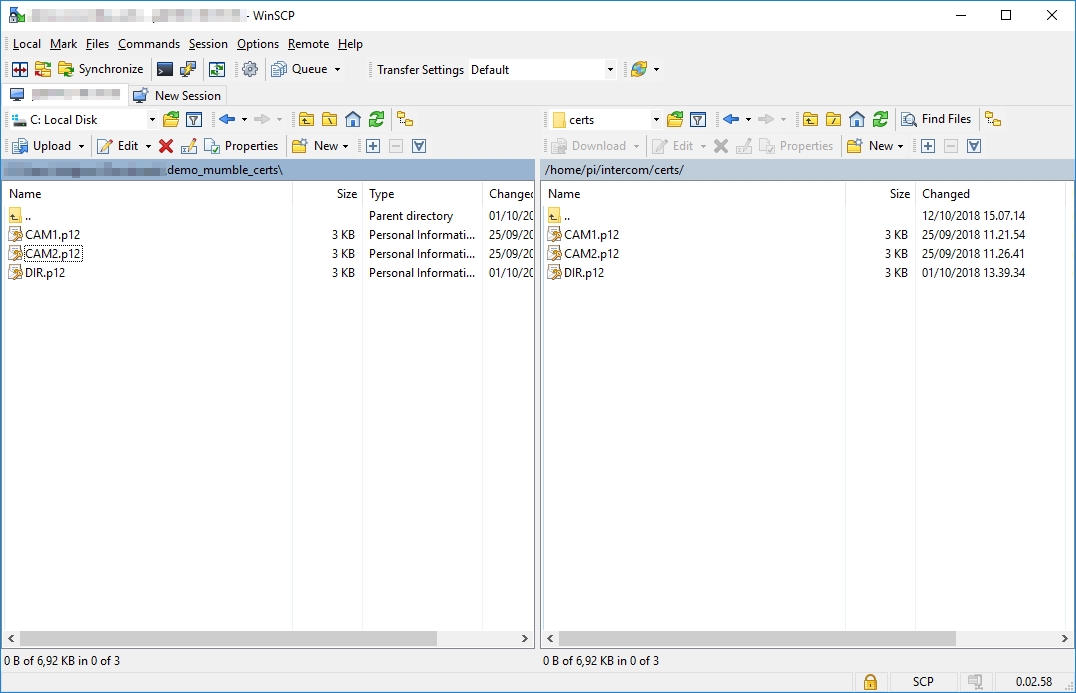
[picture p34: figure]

## 15. Install Mumble

Back to the Raspberry Pi and the terminal emulator

sudo apt install mumble

Close the terminal (click X in right corner)

## 16. Setup Mumble

When Mumble starts for the first time the Audio Tuning Wizard will appear, click next on the first introduction screen

Device selection

System: ALSA

Device [default] Playback/recording through the PulseAudio sound server

on both Input and Output device,

Uncheck positional audio -> Next

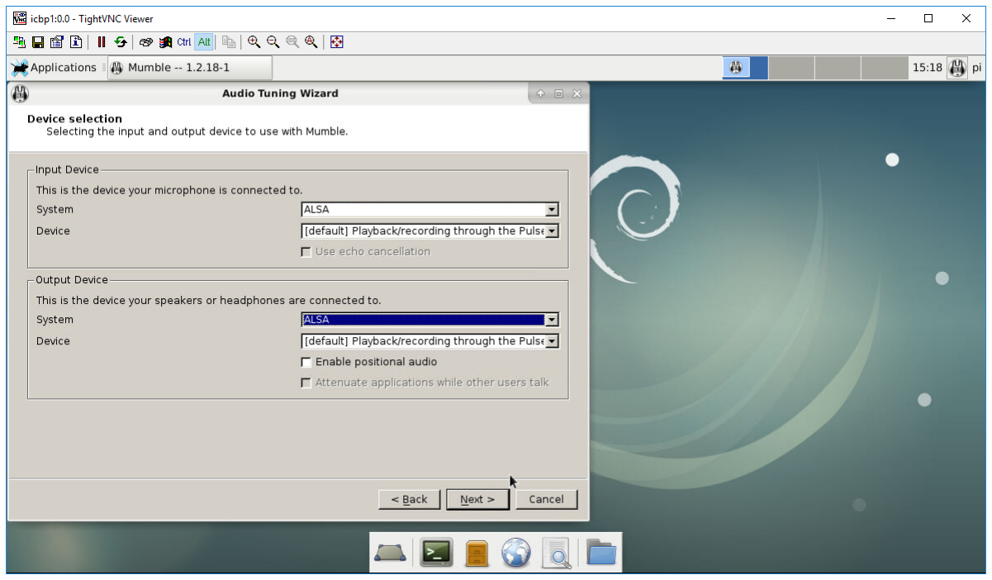
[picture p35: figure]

Set the buffer to 10ms (you will not hear anything here) -> Next

Let the microphone tuning be at its preset -> Next

Voice Activity Detection, choose Push To Talk and click the white box next to it and press CTRL + 1 -> Next

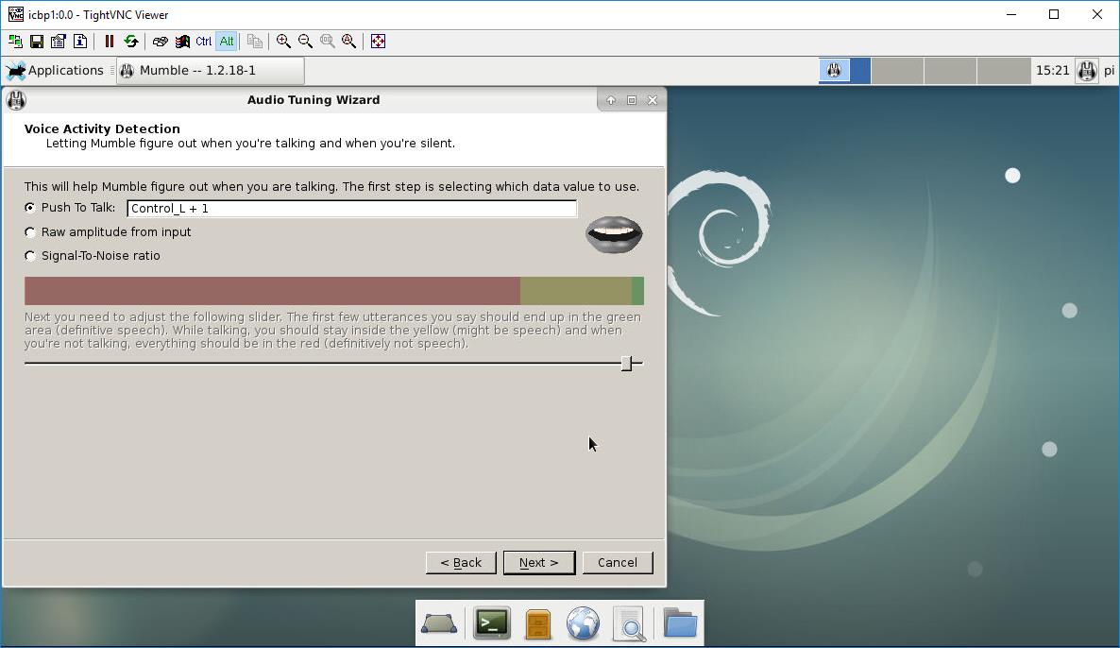
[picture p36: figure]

Quality and notifications, Quality settings -> High,

Uncheck Text-To-Speech and use sound instead -> Next

Choose if you want to submit anonymous statistics -> Finish

## 17. Import Mumble certificate

The Certificate Management should popup,

choose Import a certificate -> Next (you might have to scale the window to get to the next button)

Click Open and select the CAM1 certificate from /home/pi/intercom/certs/CAM1.p12 -> Open -> Next

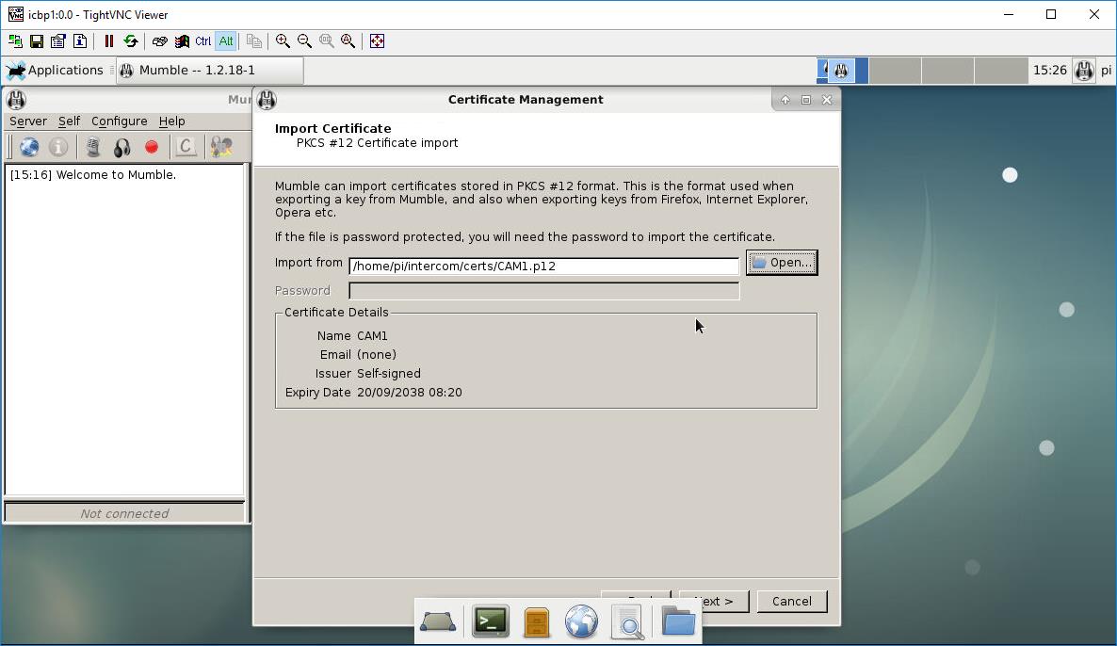
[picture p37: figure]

Click Finish

## 18. Connect to Mumble server

The Mumble Server Connect screen should have popped up, if not go to Server -> Connect

Click Add New,

Label: Intercom

Address: <YOURSERVERIP> in this example: 192.168.10.125

Port: 64738,

Username: CAM1 -> OK

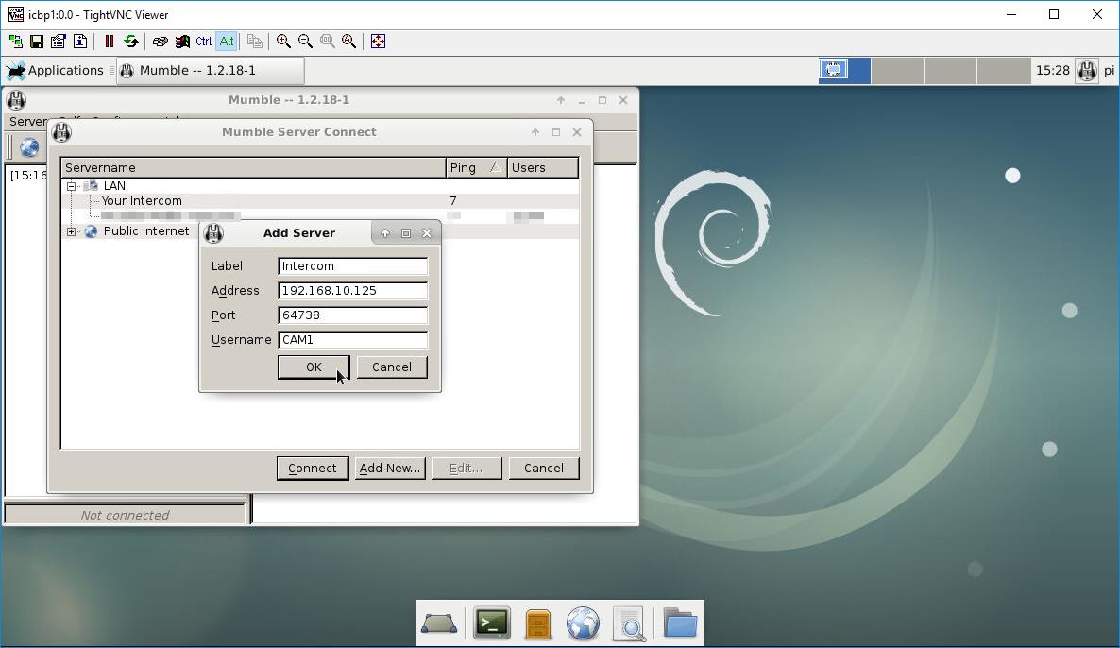
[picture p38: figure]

Under Favorite you should now see the Intercom server you just added, click Cancel and quit Mumble (Remember to ALWAYS quit/restart Mumble when making changes, settings are not saved when using poweroff/restart from command line).

Start Mumble again and connect to the Intercom server you just made, when you login to your server for the first time (with a new certificate) you will get a warning about the self-signed certificate, choose Yes and continue. You should now be logged in as CAM1 and put into the Video channel.

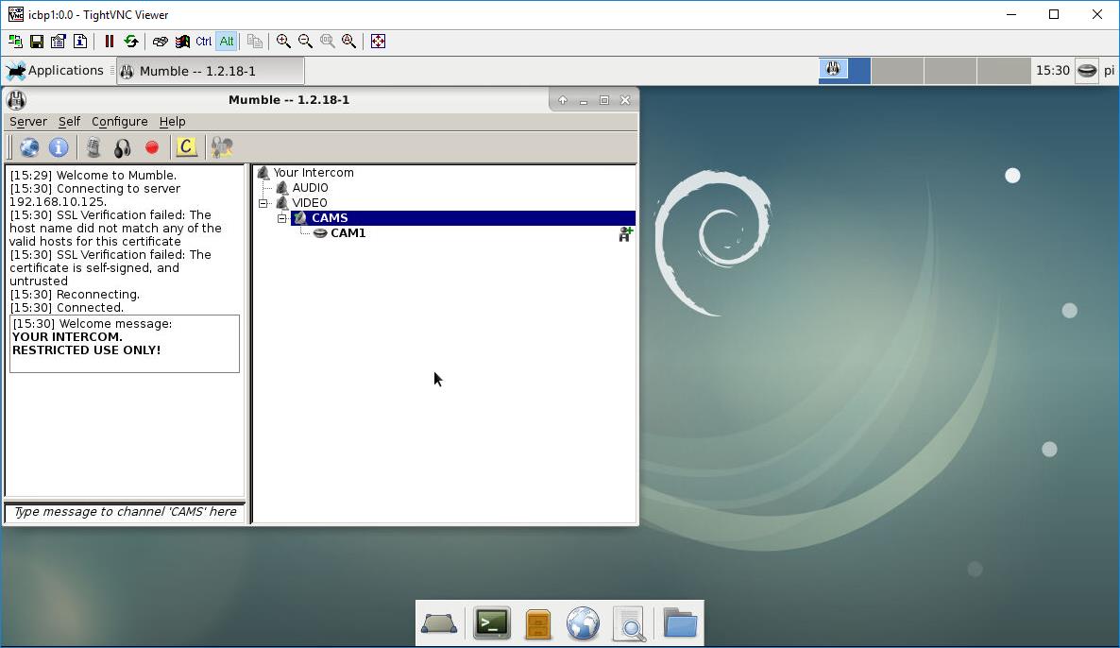
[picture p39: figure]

## 19. Continue to configure Mumble part 1

Under Configure->Settings->Click Advanced (down left)

Under Network, click Reconnect to last server on startup

Under Messages, set the matrix as in the picture, Notifications and Soundfile are the important ones, otherwise you will hear sounds every time a user joins/leaves a channel, etc.

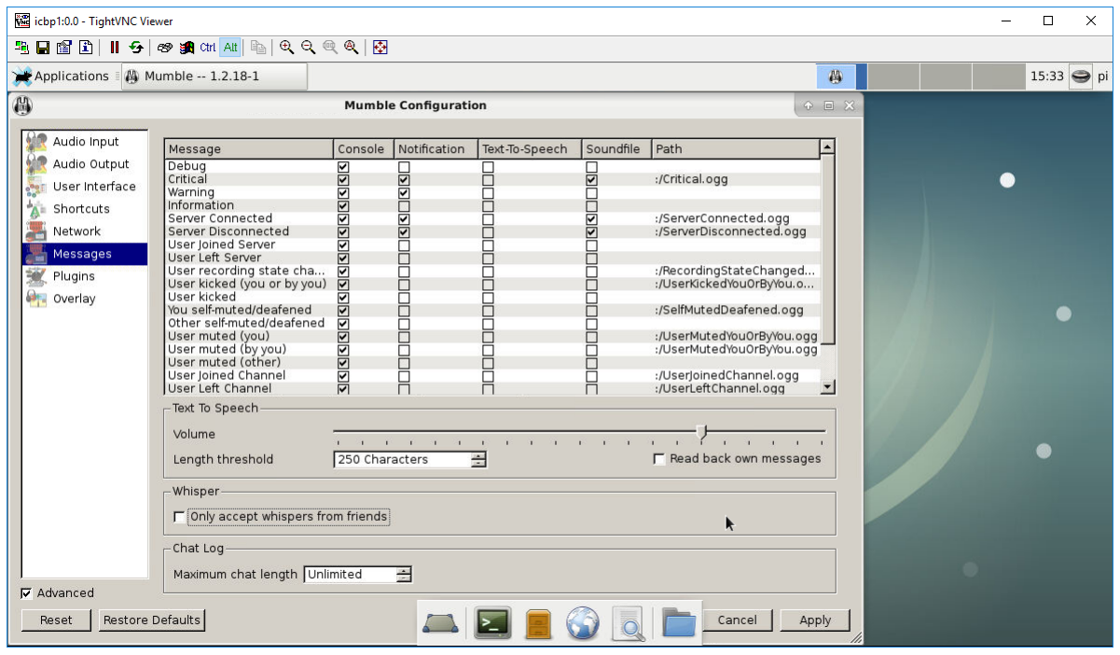
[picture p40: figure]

Apply->OK (and remember to quit/restart Mumble after this)

## 20. Autostart Mumble

Using Application->Terminal emulator (or using the terminal over ssh) do the following

sudo pico /etc/xdg/autostart/start_mumble.desktop

[Desktop Entry]
Type=Application
Name=Mumble
Comment=Start Mumble client Icon=preferences-desktop-screensaver Exec=mumble
TryExec=mumble
OnlyShowIn=XFCE;

Save file (CTRL+x) and reboot

sudo reboot

Check (with tightvnc or screen) that Mumble starts and connects to server as CAM1 after reboot.

## 21. Correct session settings

Go to Applications->Settings->Session and Startup

Uncheck Automatically save session on logout under Logout Settings, and click Close

Go to Application->Terminal Emulator and write the following command

xfce4-settings-editor


Under xfce4-session->Uncheck SaveOnExit if it is checked. Without this step, two Mumble clients will be running (one that is remembered from the last session and the new one that autostarts). Click Close and reboot once more to check that only one Mumble is running

sudo reboot

If everything is working, turn off the Raspberry Pi.

sudo poweroff

## 22. Install the Raspberry Pi into the enclosure

Consult the beltpack hardware installation guide.

## 23. Install python libraries

After the last step you can’t access the screen as the Raspberry Pi is mounted in the base station enclosure. Instead you have to connect to it with putty (under hostname enter your beltpack IP) and click Open, login with pi and your password.

Install the OLED library
sudo apt install python3-dev python3-pip libfreetype6-dev libjpeg-dev sudo pip3 install --upgrade pip
sudo pip3 install --upgrade setuptools
sudo pip3 install --upgrade luma.oled

Install GUI automation library
sudo apt install libx11-dev libxtst-dev sudo pip3 install autopy3

Install MQTT library
sudo pip3 install paho-mqtt

## 24. Copy and extract beltpack script on Raspberry Pi

Use WinSCP on your Windows computer to copy the ic_beltpack_pi3.zip file to the beltpack (/home/pi/intercom/ic_beltpack_pi3.zip).

Back in putty

cd ~/intercom
unzip ic_beltpack_pi3.zip
rm ic_beltpack_pi3.zip

## 25. Copy MQTT server certificate

login in to your server (the example server is at 192.168.10.125)

ssh pi@192.168.10.125

(answer Yes)

Copy server cert to beltpack

scp /etc/mosquitto/certs/ca.crt pi@192.168.10.152:/home/pi/intercom

(replace IP with your basestations, answer yes and enter the beltpack password)

Disconnect from server CTRL+d

ls –la
(ca.crt should now be in the folder)

## 26. Test the OLED display and connections

python3 oled_test.py
watch display when pressing buttons, CTRL+c to quit test

## 27. Test the intercom script

Before you start the script you must edit it to connect to the right IP

pico ~/intercom/ ic_beltpack_pi3.py

edit the following lines to match your setup:

mqttServer

mqttUser

mqttPass

Save file (CTRL+x) and start script

python3 ic_beltpack_pi3.py

You should now see a wifi signal meter, the text UNKNOWN and your IP on the display. CTRL+c to quit

## 28. Make intercom start script

pico ~/start_intercom.sh

#!/bin/bash

#START INTERCOM

DISPLAY=:1.0 XAUTHORITY=/home/pi/.Xauthority sudo /usr/bin/python3 /home/pi/intercom/ic_beltpack_pi3.py &

Save file (CTRL+x)

observe that there should not be a line break after python3, everything should be on the same line like python3 /home/…

chmod +x start_intercom.sh

Make the intercom script start automatically

crontab -e

(choose 2 nano if asked)

add the following line to the bottom of the file

@reboot /home/pi/start_intercom.sh

CTRL+x to exit and save changes (do not change filename)

sudo reboot

After boot you should see a signal meter, the text UNKNOWN and your IP on the display

## 29. Configure the beltpack role

On your Windows computer open a browser and go to http://YOURSERVER_IP:3000

You now need to configure the beltpack, click the wrench (the connection symbol on the left should now be green because the beltpack is online) on icbp1


Select CAM1 as Role and DIR on CH1 and CAMS on CH2 (YOU CAN ALSO CHOOSE MULTIPLE TARGETS PER CHANNEL), click Set config


Your beltpack display should now be updated accordingly, now it is time to setup Mumble to match the script role and who you can talk to.

## 30. Continue to configure Mumble part 2

Connect with tightvnc to your beltpack, you want to talk to the director (DIR) on channel 1 and all the cameras (CAMS) on channel 2.

In Mumble go to Configure -> Settings

Under Audio Input -> Compression -> Quality 96.0 kb/s

First you add the DIR Channel

Under Shortcuts - > Change Push-to-Talk to Whisper/Shout ¨

(PTT transmits only to the channel you are in)

Under Shortcuts - > Click 3 dots under Data -> Choose Shout to channel -> Click on DIR (UNDER VIDEO), ignore positional audio and OK


Then you add CAMS

Click ADD -> Double click Unassigned -> Select Whisper/shout -> Under Data click the three dots - > Choose Shout to channel -> Click on CAMS (UNDER VIDEO), ignore positional audio and OK

Click under Shortcut to assign keyboard shortcut (This should also be CTRL + 2)

The reason that DIR has its own channel is because you now can setup Mumble to talk to the director even if DIR is not connected to the server. If you choose “Whisper to list of Users” all users you want to whisper (talk to) must be connect to the server to be able to assign it.

As basestations might have some channels open all the time to for example the FM (Floor Manager) it is also a good practice to have the FM (Floor Manager) in his/her own channel. If the FM beltpack disconnects from the Mumble server even for just a second and you have the channel open from the basestation Mumble will close the connection but the basestation still shows (because the script do not know what Mumble is actually doing) that you are talking to the FM. You must then close the channel and re-open it to be able to talk to FM again. This is not necessary if FM is its own channel.


Click Apply followed by OK (and remember to quit/start Mumble again)

If you now push the switch in the direction of the display your display should say "TALK TO DIR" (if it says "TALK TO CAMS", you must swap the wires on the Raspberry Pi (36&40)) and the lips in the Mumble interface should turn blue on CAM1.


## 31. Setup the volume control

Use Winscp to transfer the file volume_control.py to /home/pi/ in the terminal, edit the file

pico /home/pi/volume_control.py

Uncomment the line that contains print(raw_adc) (remove the hashtag), CTRL+x to end editing and save

Test the script and turn the knob to position 0, take note of the value and then to 100 and take note

python3 /home/pi/volume_control.py

I got ~20680 and ~-4600 using a 100k potentiometer and a 1k resistor on the input

Now you need to update the script with these values by editing the line that starts with volume =

pico /home/pi/volume_control.py

comment the print(raw_adc) line and uncomment the print("Digital Value... line

start the script again and see if you can reach 0 and 100, if not fine tune the values above then comment out the print line.

python3 /home/pi/volume_control.py

When you are ready you need to test that everything is working all the way to the soundcard, start the script in the background and open alsamixer (the & means that you leave the script running in the background, note the pid number you get, you need it if you need to to stop the process later). If you need to stop the process later use kill and PID.

python3 /home/pi/volume_control.py &

### then start alsamixer (press F6 and choose USB Sound Device) and turn the knob to check that the soundcard volume changes from 0 to 100 (ESC to exit)

alsamixer


## 32. Edit the start_intercom.sh script

To start the volume control on boot you need to add it to the start script

pico /home/pi/start_intercom.sh

Add this line after the last line

/usr/bin/python3 /home/pi/volume_control.py &

CTRL+x to exit and save

Reboot and login and open alsamixer to check that it still works

sudo reboot

If it works you are now ready to start using the beltpack. No you can make an image of the sdcard so that you can easily duplicate it to other beltpacks.

If you have access to a linux machine, you can use ddrescue and pishrink (replace sdc with where your sd card is found, use sudo dmsg to find out)

sudo ddrescue /dev/sdc beltpack.img rescue.log

Download and read more here https://github.com/Drewsif/PiShrink

sudo pishrink.sh beltpack.img

Pishrink (without the –s) will automatically expand to use the whole sd card when started for the first time

When you deploy the image to new devices you must remember to do the following thing after deployment:

Change hostname (step 1) and IP if static IPs are used

Reboot to use the new name (and IP)

Load a new certificate in Mumble and setup who to talk to

Setup the same information in the intercom setup webgui.

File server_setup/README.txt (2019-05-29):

Files in this folder

node_intercom - Node.js files for the server
README.txt - This file
UNLICENSE - License information
setup_server.pdf - Software installation guide

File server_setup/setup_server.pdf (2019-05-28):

## Setup the software for the intercom server

Requirements:
The server can run on any hardware but in this guide we will use a Raspberry Pi 3.
Download the latest Raspbian Stretch Lite image from https://www.raspberrypi.org/downloads/raspbian/

This guide assumes that you have a basic understanding of how linux computers work and that you have access to a Windows computer (both Mac and Linux can be used but you have to find the tools needed). The setup is tested with Raspbian Stretch Lite image built on the 2018-06-27. When copying code from the blue fields remember to check that there are no whitespace characters (invisible spaces) at the end of the lines because that can break the code.

Do NOT use the placeholder passwords or IP numbers in the guide, use safe passwords that you remember and IP numbers you are allowed to use!

## Write the image to a SD card

Etcher https://etcher.io/ is recommended to write the image to the sd card. Insert the card into the Raspberry Pi, connect a keyboard and monitor and power up, after a few seconds the Raspberry will resize the partition to fill the card used and reboot. After the reboot you will see a login screen prompting for a username, use pi as username and raspberry as password. The first task is to setup the Raspberry Pi as needed. Enter the command below and press enter

sudo raspi-config

You will now see a menu like this


## 1. Configure the Raspberry

1 Change User Password (to something you remember) 2 Network Options
N1 Hostname (icserver)
4 Localisation Options
I2 Timezone
I3 Change Keyboard-Layout
5 Interfacing options
P2 SSH Enable

Reboot on exit

## 2. Set a static IP address

sudo pico /etc/dhcpcd.conf

Uncomment the example static IP configuration and use a IP that you are allowed to use
interface eth0
static ip_address=192.168.10.125/24
static routers=192.168.10.254
static domain_name_servers=8.8.8.8

Save file (CTRL+X) and reboot

sudo reboot

You should now have a IP address (look for the line My IP address is:)

You can now decide if you prefer to work with the keyboard and screen or continue the setup over SSH (using for example putty)

## 3. Update the system

sudo apt update
sudo apt dist-upgrade

## 4. Install Mumble and Mosquitto

sudo apt install mumble-server
sudo apt install mosquitto mosquitto-clients

## 5. Edit Mumble settings

Mumble is the voice chat server we use as the base for the intercom

sudo pico /etc/mumble-server.ini welcometext="<br /><b>YOUR INTERCOM.<br />RESTRICTED USE ONLY!</b><br />" serverpassword=R3plac3M3
bandwidth=150000
registerName=Your Intercom

autobanAttempts = 0
autobanTimeframe = 0
autobanTime = 300

Save file (CTRL+x)

sudo dpkg-reconfigure mumble-server

Autostart -> Yes
Higher Priority -> Yes
Set SuperUser password -> Sup3R_USER

sudo service mumble-server restart

## 6. Setup the intercom channels

The next steps require a computer with a graphical interface (Windows 10 in this example). Download and install the Mumble client (https://www.mumble.com/mumble-download.php). Start Mumble, you can close all messages (except the create certificate) that might pop up as we will not be using this client to talk to users.

Server -> Connect -> Add new
Label: SuperUser .125
Address: 192.168.10.125
Port: 64738
Username: SuperUser

Press OK and connect using the profile you just created, accept the self-signed certificate (Yes) and use the SuperUser password created earlier (Sup3R_USER in the example).

Right click to the right on the white background and choose Add to add a new channel, in this example we will make two channels AUDIO and VIDEO


Right click on the Video channel and choose Add to make a sub channel (CAMS) under VIDEO.

Repeat the last step but this time we add FM (floor manager) under VIDEO, then disconnect from the server from the menu, Server -> Disconnect

## 7. Generate intercom (Mumble) certificates

Every intercom unit needs a certificate and here is how it is done. In the guide we will only make certificates for CAM1, CAM2 and DIR. In the Mumble client, Configure -> Certificate Wizard -> Create a new certificate

Name: CAM1 (No email needed) -> Next
Replace Certificate -> Next
Export Certificate, Export to CAM1 -> Save As (make a folder called certs and save to it) Click Commit -> Finish


Now we need to connect with the new certificate to the Mumble server.

Server -> Connect -> Add New

Label: User
Address: 192.168.10.125 (use your server IP)

Port: 64738
Username: CAM1 (Use the same username as in the certificate name)

Connect with User profile just created -> Use password: R3plac3M3 Drag CAM1 into CAMS channel (VIDEO -> CAMS)
Right click CAM1 -> Register -> Yes


To create a certificate for CAM2, disconnect from the server and repeat the earlier steps

Configure -> Certificate Wizard -> Create a new certificate

Name: CAM2 (No email needed) -> Next
Replace Certificate -> Next
Export Certificate, Export to CAM2 -> Save As
Click Commit -> Finish

Server -> Connect -> Choose User from list (that you made earlier) -> Edit (Change only Username)


Connect with User profile (You are now known as CAM2 because of the changed certificate) Drag CAM2 to wanted channel (CAM2 -> VIDEO -> CAMS)
Then right click CAM2 -> Register -> Yes

Repeat the steps above for DIR (Director), and drag DIR to the VIDEO channel.

If later needed to move a user from one channel to another, just log in as that user and drag to the wanted channel. This can also be done by the SuperUser but the user must be logged in to be visible on the server.

## 8. Setup Mosquitto

Now we need to get back to the Raspberry Pi command line to generate SSL certificates for Mosquitto that is used for delivering messages between all the intercom devices. Mosquitto is a MQTT broker that we use for communication between the intercom devices, the MQTT protocol is a machine to machine / IoT connectivity protocol.

mkdir ~/certs
cd ~/certs

Next we will use a ready-made script to generate a self-signed certificate.

wget https://raw.githubusercontent.com/owntracks/tools/master/TLS/generate-CA.sh

We need to change IP and hostname in the script

pico generate-CA.sh

Uncomment and change the following lines, use your server IP and hostname
IPLIST="192.168.10.125"
HOSTLIST="icserver"

Save the file (CTRL+x), add execution rights to the script and run it.

chmod +x generate-CA.sh
./generate-CA.sh

Copy the SSL certificates to the right place for Mosquitto (if you used another server name (not icserver), as in this guide the files will have other names)

sudo cp ca.crt /etc/mosquitto/certs/
sudo cp icserver.crt /etc/mosquitto/certs/
sudo cp icserver.key /etc/mosquitto/certs/

Make the Mosquitto config file

sudo pico /etc/mosquitto/conf.d/icserver.conf

user mosquitto

queue_qos0_messages false
persistent_client_expiration 2h allow_duplicate_messages false

protocol mqtt
listener 8883
cafile /etc/mosquitto/certs/ca.crt certfile /etc/mosquitto/certs/icserver.crt keyfile /etc/mosquitto/certs/icserver.key tls_version tlsv1

autosave_interval 1800
allow_anonymous true

Save the file (CTRL+x) and restart the Mosquitto server

sudo service mosquitto restart

Check that the Mosquitto server is running

ps aux | grep mosquito

Should output something like this if the server is running
mosquit+ 1094 0.0 0.4 8232 4620 ? S 15:44 0:00 /usr/sbin/mosquitto -c /etc/mosquitto/mosquitto.conf
pi 1102 0.0 0.0 4372 560 pts/0 S+ 15:45 0:00 grep --color=auto mosquito

Now try to publish something to the server to check that it works (everything must be on the same line)

mosquitto_pub -h 127.0.0.1 --cafile ~/certs/ca.crt -p 8883 -t "test" -m "Hello World" -r --tls-version tlsv1

No output means that it works, now try to subscribe to the message we sent.

mosquitto_sub -h 127.0.0.1 --cafile ~/certs/ca.crt -p 8883 -t "test" --tls-version tlsv1

The output show now be “Hello World”, (CTRL+c) to stop. Next we need to setup username and password for the mosquito user.

sudo pico /etc/mosquitto/conf.d/icserver.conf

Change allow anonymous to false and add the password and acl lines

allow_anonymous false
password_file /etc/mosquitto/pwfile
acl_file /etc/mosquitto/acl

Make the user file

sudo pico /etc/mosquitto/acl

user intercom
topic readwrite media/intercom/#

Generate a password for the intercom user (NOTE! Only use –c if the pwfile does NOT exist)

sudo mosquitto_passwd -c /etc/mosquitto/pwfile intercom

Here we use _Interc0M_ as password but use your own and take note as you will need it later, restart

sudo service mosquitto restart

Try to publish again with the username/password created (on one line again)

mosquitto_pub -h 127.0.0.1 --cafile ~/certs/ca.crt -p 8883 -t "test" -m "Hello 2!" -r -u intercom -P _Interc0M_ --tls-version tlsv1

If everything works you should not get any output, subscribe to check the result.

mosquitto_sub -h 127.0.0.1 --cafile ~/certs/ca.crt -p 8883 -t "test" -u intercom -P _Interc0M_ --tls-version tlsv1

You should now see “Hello 2!”, CTRL+c to quit

## 9. Install Node.js

cd ~/
sudo apt-get install curl
curl -sL https://deb.nodesource.com/setup_8.x | sudo -E bash -
sudo apt-get install nodejs

Test that node installed correctly

nodejs –v

Outputs the installed version (v8.12.0 in my case)

## 10. Install node.js app

mkdir ~/nodeapps
mkdir ~/nodeapps/intercom
cd ~/nodeapps/intercom

Go to your Windows computer and copy the node app files (node_intercom.zip) with for example the WinSCP software to /home/pi/nodeapps/intercom/

Download WinSCP (https://winscp.net/) on your Windows computer, install and start.

Under session choose SCP host name is your server IP,

User name: pi, Password: (set in step 1)

When you are logged into the server, on the left side you go to the folder where you downloaded the intercom files

On the right side you have your server, double click on nodeapps and then intercom

Select the node_intercom.zip on the left side, right click and select Upload and OK


Go back to the Raspberry Pi command line and unzip the files just uploaded

unzip node_intercom.zip

Enter the intercom folder and install needed modules (based on the package.json file)

cd ~/nodeapps/intercom
npm install

Edit the intercom.js file under connectOptions to change the host (your server IP), username and password. This is also the file you need to change if you want more devices and roles in the future.

pico ~/nodeapps/intercom/intercom.js

CTRL+x to save and try to start the intercom app

node intercom.js

The output should be “listening on *:3000 and Connected to MQTT server”, CTRL+c to stop. If everything works, we now need to start the intercom app on boot.

pico ~/start_node.sh

#!/bin/bash

/usr/bin/node /home/pi/nodeapps/intercom/intercom.js &

CTRL+x to save and then we need to give execute rights to the file

chmod +x ~/start_node.sh

Add script to crontab to start on boot (if it is the first time you use crontab, choose nano)

crontab -e

Add after last line

@reboot /home/pi/start_node.sh

CTRL+x to save and reboot

sudo reboot

When the server has rebooted, log in and check that the intercom app is running

ps aux | grep node

The output should be similar to this

pi 971 14.7 3.6 120600 34404 pts/0 Sl 13:55 0:01 /usr/bin/node /home/pi/nodeapps/intercom/intercom.js
pi 983 0.0 0.0 4372 572 pts/0 R+ 13:55 0:00 grep --color=auto node

Congratulations, the server is setup.

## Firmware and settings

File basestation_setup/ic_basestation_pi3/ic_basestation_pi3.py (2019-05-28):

import RPi.GPIO as GPIO
from luma.core.interface.serial import i2c, spi
from luma.core.render import canvas
from luma.oled.device import ssd1306
from PIL import ImageFont, ImageDraw, Image
from signal import *
from threading import Thread
import paho.mqtt.client as mqtt
import autopy3, os, socket, subprocess, sys, time, datetime, smbus2

#################################################################
################# BASESTATION USER CONFIGURATION ################
### INTERCOM CONFIGURATION
### WHO USES THIS BASESTATION ###
icUser = ""
### THIS DEVICE HAS 8 CHANNELS ["","","","","","","",""] (3 CHANNELS -> ["","",""])
icTalkTo = [" "," "," "," "," "," "," "," "]
oledIcTalkTo = ["","","","","","","",""]
### MQTT SETTINGS
mqttServer = "192.168.10.125"
mqttPort = 8883
mqttTimeOut = 10
mqttUser = "intercom"
mqttPass = "_Interc0M_"
########## PLEASE DO NOT MAKE CHANGES BELOW THIS LINE! ##########
#################################################################

### NETWORK INTERFACE USED
interface = "eth0"
### URL CONFIGURATION
statusInterval = 5000 ### UPDATE INTERVAL FOR MQTT (IN MILLISECONDS)
### Software version
icSoftVerText = "SW v1.1"

os.environ['DISPLAY'] = ':0.0'

font1 = ImageFont.truetype('/home/pi/intercom/fonts/VeraMoBd.ttf',27)
font2 = ImageFont.truetype('/home/pi/intercom/fonts/VeraMoBd.ttf',16)
font3 = ImageFont.truetype('/home/pi/intercom/fonts/VeraMoBd.ttf',12)

### GET DEVICE HOSTNAME
deviceHostName = socket.gethostname()
### SET DEVICE IP
deviceIP = "N/A"

### INITIALIZE GPIO AND ACTIVATE PULL DOWN ON INPUTS
GPIO.setwarnings(False)
GPIO.setmode(GPIO.BOARD)
### Power Off buttons
powPort = 19
GPIO.setup(powPort, GPIO.IN, pull_up_down=GPIO.PUD_DOWN)
### PTT buttons
pttPorts = (31,32,33,35,36,37,38,40)
GPIO.setup(pttPorts, GPIO.IN, pull_up_down=GPIO.PUD_DOWN)
### OLED MUX
muxPorts = (23,24,26)
GPIO.setup(muxPorts, GPIO.OUT)
### SET MUX TO ADDRESS 0x70
GPIO.output(23, 0)
GPIO.output(24, 0)
GPIO.output(26, 0)

### INITIALIZE SCRIPT SETTINGS
mqttStatus = 3
mqttStatusCodes=["SUCCESS","INCOR PROT","INVAL CLNT","SRV UNAVAIL","BAD US/OW","NOT AUTH"]
lastPTT = ["low","low","low","low","low","low","low","low"]
oledLastPTT = ["","","","","","","",""]
lastPTTLow = [0,0,0,0,0,0,0,0]
lastPTTHigh = [0,0,0,0,0,0,0,0]
talkList = []
talksToMe = []
talksToMeState = [0,0,0,0,0,0,0,0]
lastTalkList = "0"
lastIcTalk = [0,0,0,0,0,0,0,0]
pttLocked = ["","","","","","","",""]
lastPO = int(round(time.time() * 1000))
poOK = False
updateOLED = True
lastStatusSent = 0

def multiIcTalkTo(input,ch):
  global lastIcTalk
  multi = input.split(",")
  if lastIcTalk[ch] < len(multi):
    output = multi[lastIcTalk[ch]]
    lastIcTalk[ch] += 1
  else:
    output = multi[0]
    lastIcTalk[ch] = 1
  return output

def oledUpdate():
  global icTalkTo
  global lastPTT
  global updateOLED
  global talksToMe
  while updateOLED == True:
    oledPort = [0x01,0x02,0x04,0x08]
    channelOrder = [0,4,1,5,2,6,3,7]
    channelPointer = 0
    ### LOOP THRU ALL 4 DISPLAYS
    for x in range(0, 4):
      bus.write_byte(0x70, oledPort[x])
      with canvas(device) as draw:
        ### OLED UPPER PART
        if lastPTT[channelOrder[channelPointer]] == "low":
          ### MULTIPLE TALK TO ADDRESSES?
          tmpTalk = []
          if icTalkTo[channelOrder[channelPointer]].find(",") != -1:
            talkTo = multiIcTalkTo(icTalkTo[channelOrder[channelPointer]],channelOrder[channelPointer])
            tmpTalk = icTalkTo[channelOrder[channelPointer]].split(',')
          else:
            talkTo = icTalkTo[channelOrder[channelPointer]]
            tmpTalk.append(icTalkTo[channelOrder[channelPointer]])
          ### TALKING TO ME?
          isTalking = False
          for s in talksToMe:
            for talk in tmpTalk:
              if talk == "CAMS":
                if talk[:3] in s:
                  isTalking = True
              elif talk == s:
                isTalking = True
          if isTalking == True and talksToMeState[channelOrder[channelPointer]] == 0:
            #oledDraw(display,ud,talkTo,talkedTo,isTalking)
            draw.rectangle((0,0,127,32), outline=0, fill=255)
            textSize=draw.textsize(talkTo, font=font2)
            draw.text(((128-textSize[0])/2, 8), talkTo, font=font2, fill=0)
            talksToMeState[channelOrder[channelPointer]] = 1
          else:
            textSize=draw.textsize(talkTo, font=font2)
            draw.text(((128-textSize[0])/2, 8), talkTo, font=font2, fill=255)
            talksToMeState[channelOrder[channelPointer]] = 0
        else:
          tmpTalk = []
          if icTalkTo[channelOrder[channelPointer]].find(",") != -1:
            talkTo = multiIcTalkTo(icTalkTo[channelOrder[channelPointer]],0)
            tmpTalk = icTalkTo[channelOrder[channelPointer]].split(',')
          else:
            talkTo = icTalkTo[channelOrder[channelPointer]]
            tmpTalk.append(icTalkTo[channelOrder[channelPointer]])
          ### TALKING TO ME?
          isTalking = False
          for s in talksToMe:
            for talk in tmpTalk:
              if talk == "CAMS":
                if talk[:3] in s:
                  isTalking = True
              elif talk == s:
                isTalking = True
          if isTalking == True and talksToMeState[channelOrder[channelPointer]] == 0:
            draw.rectangle((0,0,127,32), outline=0, fill=255)
            logo = Image.open('/home/pi/intercom/images/send_left.png')
            draw.bitmap((2, 8), logo, fill=0)
            textSize=draw.textsize(talkTo, font=font2)
            draw.text(((128-textSize[0])/2, 8), talkTo, font=font2, fill=0)
            logo = Image.open('/home/pi/intercom/images/send_right.png')
            draw.bitmap((106, 8), logo, fill=0)
            talksToMeState[channelOrder[channelPointer]] = 1
          else:
            logo = Image.open('/home/pi/intercom/images/send_left.png')
            draw.bitmap((2, 8), logo, fill=255)
            textSize=draw.textsize(talkTo, font=font2)
            draw.text(((128-textSize[0])/2, 8), talkTo, font=font2, fill=1)
            logo = Image.open('/home/pi/intercom/images/send_right.png')
            draw.bitmap((106, 8), logo, fill=255)
            talksToMeState[channelOrder[channelPointer]] = 0
        channelPointer+=1

        ### OLED LOWER PART
        if lastPTT[channelOrder[channelPointer]] == "low":
          tmpTalk = []
          if icTalkTo[channelOrder[channelPointer]].find(",") != -1:
            talkTo = multiIcTalkTo(icTalkTo[channelOrder[channelPointer]],channelOrder[channelPointer])
            tmpTalk = icTalkTo[channelOrder[channelPointer]].split(',')
          else:
            talkTo = icTalkTo[channelOrder[channelPointer]]
            tmpTalk.append(icTalkTo[channelOrder[channelPointer]])
          ### TALKING TO ME?
          isTalking = False
          for s in talksToMe:
            for talk in tmpTalk:
              if talk == "CAMS":
                if talk[:3] in s:
                  isTalking = True
              elif talk == s:
                isTalking = True
          if isTalking == True and talksToMeState[channelOrder[channelPointer]] == 0:
            draw.rectangle((0,33,127,64), outline=0, fill=255)
            textSize=draw.textsize(talkTo, font=font2)
            draw.text(((128-textSize[0])/2, 40), talkTo, font=font2, fill=0)
            talksToMeState[channelOrder[channelPointer]] = 1
          else:
            textSize=draw.textsize(talkTo, font=font2)
            draw.text(((128-textSize[0])/2, 40), talkTo, font=font2, fill=255)
            talksToMeState[channelOrder[channelPointer]] = 0
        else:
          tmpTalk= []
          if icTalkTo[channelOrder[channelPointer]].find(",") != -1:
            talkTo = multiIcTalkTo(icTalkTo[channelOrder[channelPointer]],channelOrder[channelPointer])
            tmpTalk = icTalkTo[channelOrder[channelPointer]].split(',')
          else:
            talkTo = icTalkTo[channelOrder[channelPointer]]
            tmpTalk.append(icTalkTo[channelOrder[channelPointer]])
          ### TALKING TO ME?
          isTalking = False
          for s in talksToMe:
            for talk in tmpTalk:
              if talk == "CAMS":
                if talk[:3] in s:
                  isTalking = True
              elif talk == s:
                isTalking = True
          if isTalking == True and talksToMeState[channelOrder[channelPointer]] == 0:
            draw.rectangle((0,33,127,64), outline=0, fill=255)
            logo = Image.open('/home/pi/intercom/images/send_left.png')
            draw.bitmap((2, 40), logo, fill=0)
            textSize=draw.textsize(talkTo, font=font2)
            draw.text(((128-textSize[0])/2, 40), talkTo, font=font2, fill=0)
            logo = Image.open('/home/pi/intercom/images/send_right.png')
            draw.bitmap((106, 50), logo, fill=0)
            talksToMeState[channelOrder[channelPointer]] = 1
          else:
            logo = Image.open('/home/pi/intercom/images/send_left.png')
            draw.bitmap((2, 40), logo, fill=255)
            textSize=draw.textsize(talkTo, font=font2)
            draw.text(((128-textSize[0])/2, 40), talkTo, font=font2, fill=1)
            logo = Image.open('/home/pi/intercom/images/send_right.png')
            draw.bitmap((106, 40), logo, fill=255)
            talksToMeState[channelOrder[channelPointer]] = 0
        channelPointer+=1
    time.sleep(0.1)

def clearBG(type):
  global updateOLED
  ### START/STOP DISPLAY FUNCTION
  if type == "Start":
    with canvas(device) as draw:
      icStartText_size=draw.textsize("Intercom", font=font2)
      draw.text(((128-icStartText_size[0])/2, 5), "Intercom", font=font2, fill=255)
      icStartText_size=draw.textsize("starting", font=font2)
      draw.text(((128-icStartText_size[0])/2, 25), "starting", font=font2, fill=255)
      icSoftVerText_size=draw.textsize(icSoftVerText, font=font2)
      draw.text(((128-icSoftVerText_size[0])/2, 45), icSoftVerText, font=font2, fill=255)
    time.sleep(4)

  if type == "Stop":
    updateOLED = False
    time.sleep(1)
    bus.write_byte(0x70, 0xFF)
    with canvas(device) as draw:
      draw.rectangle((0, 0, device.width, device.height), outline=0, fill=0)
    bus.write_byte(0x70, 0xFF)
    with canvas(device) as draw:
      draw.rectangle((0, 0, device.width, device.height), outline=0, fill=0)
      logo = Image.open('/home/pi/intercom/images/made_in_arcada_1bit_shutdown.png')
      draw.bitmap((0, 0), logo, fill=1)
    time.sleep(2)
    with canvas(device) as draw:
      draw.rectangle((0, 0, device.width, device.height), outline=0, fill=0)
    GPIO.cleanup()

def getIPInfo():
  ### GET DEVICE IP
  deviceIP = "N/A"
  try:
    intf = interface
    deviceIP = str(subprocess.check_output(['hostname', '--all-ip-addresses']).rstrip().decode())
    if deviceIP == "" or deviceIP.split(".")[0] == "169":
      deviceIP = "N/A"
    return {'deviceIP':deviceIP}
  except:
    return {'deviceIP':deviceIP}
    pass

def clean(*args):
  ### EXECUTE WHEN SCRIPT IS ABORTED
  print ("\nScript aborted")
  ### STOP BROADCASTING ON ALL ACTIVE CHANNELS
  for index in range(len(lastPTT)):
    if lastPTT[index] == "high":
      autopy3.key.toggle(str(index+1), False, autopy3.key.MOD_CONTROL)
      lastPTT[index] = "low"
  client.publish("media/intercom/status/" + deviceHostName + "/state", "OFFLINE", qos=1, retain=True)
  client.disconnect()
  clearBG("Stop")
  sys.exit(0)

def on_connect(client, userdata, flags, rc):
  print("MQTT connected...")
  global mqttStatus
  mqttStatus = rc
  client.publish("media/intercom/status/" + deviceHostName + "/state", "ONLINE", qos=1, retain=True)
  client.publish("media/intercom/status/" + deviceHostName + "/deviceChannels", len(icTalkTo), qos=1, retain=True)
  ### SUBSCRIBE TO ROLE (icUser)
  client.subscribe("media/intercom/setup/" + deviceHostName + "/deviceRole", qos=1)
  client.subscribe("media/intercom/broadcast/+/talk", qos=1)
  chCounter = 1
  for ch in icTalkTo:
    client.subscribe("media/intercom/setup/" + deviceHostName + "/channel/" + str(chCounter), qos=1)
    chCounter += 1

def on_disconnect(client, userdata, rc):
  print("MQTT disconnected!!")
  global mqttStatus
  mqttStatus = rc

def on_message(client, userdata, message):
  if message.topic == "media/intercom/setup/" + deviceHostName + "/deviceRole":
    global icUser
    icUser = str(message.payload.decode())
    client.publish("media/intercom/status/" + deviceHostName + "/deviceRole", icUser, qos=1, retain=True)

  if "media/intercom/setup/" + deviceHostName + "/channel/" in message.topic:
    chCounter = 1
    global icTalkTo
    for ch in icTalkTo:
      if message.topic == "media/intercom/setup/" + deviceHostName + "/channel/" + str(chCounter):
        icTalkTo[chCounter-1] = str(message.payload.decode())
        client.publish("media/intercom/status/" + deviceHostName + "/channel/" + str(chCounter), icTalkTo[chCounter-1], qos=1, retain=True)
      chCounter += 1

  if "media/intercom/broadcast/" and "/talk" in message.topic:
    global talksToMe
    print(message.topic)
    print(message.payload.decode())

    talks = False
    talkFrom = message.topic.replace("media/intercom/broadcast/","")
    talkFrom = talkFrom.replace("/talk","")

    if b"," not in message.payload:
      otherToMe = [""]
      otherToMe[0] = str(message.payload.decode())
    else:
      otherToMe = [""]
      otherToMe = str(message.payload.decode().split(','))

    if icUser in otherToMe:
      talks = True

    if talks == True:
      talksToMe.append(talkFrom)
    else:
      if talkFrom in talksToMe:
        talksToMe.remove(talkFrom)

bus = smbus2.SMBus(1)
bus.write_byte(0x70, 0xFF)
device = ssd1306(port=0, address=0x3c, rotate=0)

clearBG("Start")

### OWN THREAD FOR OLED UPDATE
try:
   t = Thread(target=oledUpdate, args=())
   t.start()
except:
   print("Error: unable to start thread")

def connectMQTT():
  ### MQTT connection
  try:
    client.connect_async(mqttServer, mqttPort, mqttTimeOut)
    client.on_connect = on_connect
    client.on_message = on_message
    client.on_disconnect = on_disconnect
    client.loop_start()
  except:
    pass

client = mqtt.Client(client_id=deviceHostName, clean_session=False, userdata=None)
client.tls_set("/home/pi/intercom/ca.crt")
### USE INSECURE IF YOUR CERTIFICATE IS SELF SIGNED
client.tls_insecure_set(True)
client.username_pw_set(mqttUser, password=mqttPass)
client.will_set("media/intercom/status/" + deviceHostName + "/state", "OFFLINE", qos=1, retain=True)

while True:
  ### DO WE HAVE AN IP ADDRESS?
  if deviceIP == "N/A":
    icTalkTo[0] = "NO IP"
    deviceInfo = getIPInfo()
    deviceIP = deviceInfo['deviceIP']
  ### IS MQTT CONNECTED?
  if mqttStatus > 0:
    if deviceIP == "N/A":
      icTalkTo[0]="NO IP"
    else:
      icTalkTo[0]=deviceIP
    icTalkTo[4]=mqttStatusCodes[mqttStatus]
    if deviceIP != "N/A":
      icTalkTo[0]=deviceIP
      connectMQTT()
  for keyCounter, portNum in enumerate(pttPorts):
    if GPIO.input(portNum) == 1:
      if lastPTTHigh[keyCounter] == 0:
        lastPTTHigh[keyCounter] = int((time.time() + 0.5) * 1000)
      if lastPTT[keyCounter] == "low" or lastPTT[keyCounter] == "":
        ### PUSH AND HOLD "CTRL + 1" ###
        autopy3.key.toggle(str(keyCounter+1), True, autopy3.key.MOD_CONTROL)
        lastPTT[keyCounter] = "high"
      lastPTTLow[keyCounter] = 0
    else:
      if lastPTTLow[keyCounter] == 0:
        lastPTTLow[keyCounter] = int((time.time() + 0.5) * 1000)
        ### CHECK IF PTT PRESS WAS SHORT
        if lastPTTHigh[keyCounter] + 600 >= lastPTTLow[keyCounter]:
          if pttLocked[keyCounter] == True:
            pttLocked[keyCounter] = False
          else:
            pttLocked[keyCounter] = True
        else:
          pttLocked[keyCounter] = False
      ### IF lastPTT[x] LAST STATE WAS HIGH AND lastPTT[x] PTT STATE IS NOT LOCKED -> SET lastPTT[x] LOW ###
      if (lastPTT[keyCounter] == "high" or lastPTT[keyCounter] == "") and pttLocked[keyCounter] == False:
        ### RELEASE "CTRl + 1" ###
        autopy3.key.toggle(str(keyCounter+1), False, autopy3.key.MOD_CONTROL)
        lastPTT[keyCounter] = "low"
        ### Loop to ensure that all active channels are broadcasting
        for index in range(len(lastPTT)):
          if lastPTT[index] == "high":
            autopy3.key.toggle(str(index+1), True, autopy3.key.MOD_CONTROL)
      lastPTTHigh[keyCounter] = 0
  talkList = []
  for idx, val in enumerate(lastPTT):
    if val == "high":
      talkList.append(icTalkTo[idx])

  ### TURN OFF SYSTEM IF POWER OFF BUTTON IS PRESSED FOR 3 OR MORE SECONDS
  if GPIO.input(powPort) == 1:
    if (lastPO <= int(round(time.time() * 1000)) - 3000) and poOK == False:
      poOK = True
      ### STOP BROADCASTING ON ALL ACTIVE CHANNELS
      for index in range(len(lastPTT)):
        if lastPTT[index] == "high":
          autopy3.key.toggle(str(index+1), False, autopy3.key.MOD_CONTROL)
          lastPTT[index] = "low"
      client.publish("media/intercom/status/" + deviceHostName + "/state", "OFFLINE", qos=1, retain=True)
      client.disconnect()
      clearBG("Stop")
      os.system('poweroff')
      sys.exit(0)
  else:
    poOK = False
    lastPO = int(round(time.time() * 1000))

  ### PUBLISH TALK STATUS TO MQTT SERVER
  if (icUser != ""):
    if (','.join(talkList) != lastTalkList):
      if len(talkList) == 0:
        result = client.publish("media/intercom/broadcast/" + icUser + "/talk", "NOT TALKING", qos=1, retain=True)
      else:
        result = client.publish("media/intercom/broadcast/" + icUser + "/talk", ','.join(talkList), qos=1, retain=True)
      # TODO CHECK IF MESSAGE WAS RECEIVED
      lastTalkList = ','.join(talkList)


  if (lastStatusSent == 0 or int(round(time.time() * 1000))-statusInterval >= lastStatusSent):
      ### Publish device status
      lastStatusSent = int(round(time.time() * 1000))
      client.publish("media/intercom/status/" + deviceHostName + "/deviceRole", icUser, qos=1, retain=True)
      client.publish("media/intercom/status/" + deviceHostName + "/deviceChannels", len(icTalkTo), qos=1, retain=True)
      chCount = 1
      for chData in icTalkTo:
        client.publish("media/intercom/status/" + deviceHostName + "/channel/" + str(chCount), chData, qos=1, retain=True)
        chCount += 1

  ### WAIT FOR 100 MS BEFORE START THE LOOP AGAIN ###
  time.sleep(0.1)

  ### CATCH INTERRUPTIONS ###
  for sig in (SIGINT, SIGTERM, SIGABRT, SIGILL, SIGHUP, SIGSEGV):
    signal(sig, clean)

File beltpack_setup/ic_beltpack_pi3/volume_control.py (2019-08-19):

import smbus2, subprocess, time

lastVolume = 0
bus=smbus2.SMBus(1)

def translate(sensor_val, in_from, in_to, out_from, out_to):
    out_range = out_to - out_from
    in_range = in_to - in_from
    in_val = sensor_val - in_from
    val=(float(in_val)/in_range)*out_range
    out_val = out_from+val
    return out_val

while True:
  data = [0x84,0x83]
  bus.write_i2c_block_data(0x4a, 0x01, data)
  data = bus.read_i2c_block_data(0x4a,0x00, 2)
  raw_adc = data[0] * 256 + data[1]
  if raw_adc > 32767:
    raw_adc -= 65535
  # UNCOMMENT NEXT LINE FOR FINE-TUNING OF POTENTIOMETER
  #print(raw_adc)
  # Translate analog input from 0 to 100
  volume = int(translate(raw_adc,20680,-4600,0,100))
  if lastVolume <= volume -2 or lastVolume >= volume + 2:
    # UNCOMMENT NEXT LINE TO CHECK DATA FED INTO SOUNDCARD
    #print("Digital Value of Analog Input : %d" %volume)
    subprocess.Popen('amixer -q -c1 set Speaker ' + str(volume) + '%', shell=True)
    lastVolume = volume
  time.sleep(0.25)
